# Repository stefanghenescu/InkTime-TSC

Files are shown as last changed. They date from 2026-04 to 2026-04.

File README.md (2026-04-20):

# InkTime TSC

## Block Diagram
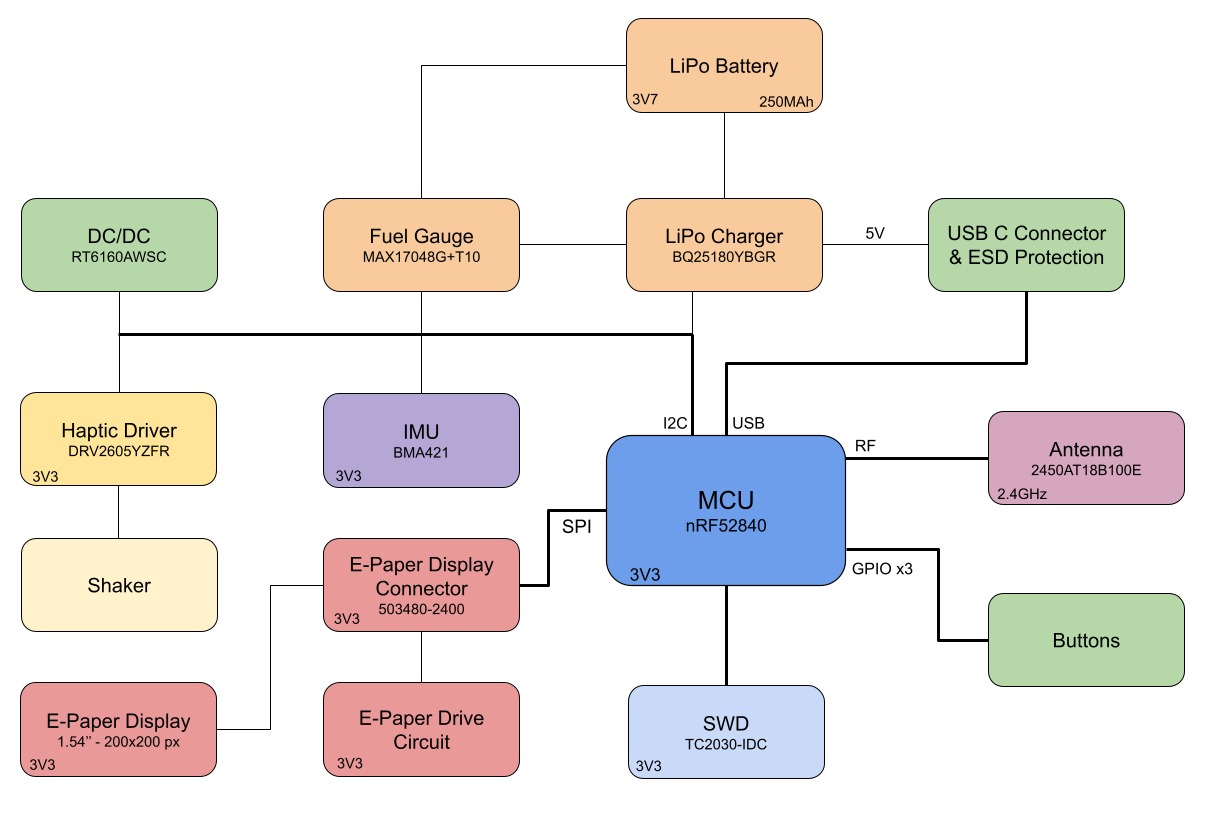
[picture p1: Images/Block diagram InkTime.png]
Block Diagram


---

## Bill of Materials (BOM)

| Name | Component Type | Package | Part Number / Value | Qty | JLCPCB Part Link | Datasheet Link |
| :--- | :--- | :--- | :--- | :--- | :--- | :--- |
| **U1** | MCU | AQFN-74 | NRF52840 | 1 | [View Part](https://jlcpcb.com/partdetail/NordicSemicon-NRF52840_QIAAR/C190794) | [View Datasheet](https://resources.ampheo.com/static/datasheets/nordic-semiconductor/nrf52840-qiaa-r-rev2.pdf) |
| **IC1** | LiPo Charger | DSBGA-8 | BQ25180YBGR | 1 | [View Part](https://jlcpcb.com/partdetail/TexasInstruments-BQ25180YBGR/C3682423) | [View Datasheet](https://www.ti.com/lit/ds/symlink/bq25180.pdf?ts=1776583277258) |
| **IC2** | Haptic Driver | DSBGA-9 | DRV2605YZFR | 1 | [View Part](https://jlcpcb.com/partdetail/TexasInstruments-DRV2605YZFR/C81079) | [View Datasheet](https://www.ti.com/lit/ds/symlink/drv2605.pdf) |
| **IC3** | IMU / Accelerometer | LGA-12 | BMA423 | 1 | [View Part](https://jlcpcb.com/partdetail/BoschSensortec-BMA421/C5242966) | [View Datasheet](https://files.pine64.org/doc/datasheet/pinetime/BST-BMA421-FL000.pdf) |
| **IC9** | DC/DC Converter | 15-WL-CSP | RT6160AWSC | 1 | [View Part](https://jlcpcb.com/partdetail/RichtekTech-RT6160AWSC/C7065276) | [View Datasheet](https://www.lcsc.com/datasheet/C7065276.pdf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) |
| **U3** | Fuel Gauge | TDFN-8 | MAX17048G+T10 | 1 | [View Part](https://jlcpcb.com/partdetail/2777647-MAX17048GT10/C2682616) | [View Datasheet](https://www.analog.com/media/en/technical-documentation/data-sheets/max17048-max17049.pdf) |
| **ANT1** | Chip Antenna | ANTC3216 | 2450AT18B100E | 1 | [View Part](https://jlcpcb.com/partdetail/JohansonDielectrics-2450AT18B100E/C2917717) | [View Datasheet](https://www.johansontechnology.com/docs/1187/2450AT18B100_X8XXogU.pdf) |
| **J1** | FPC Connector | 5034802400 | 503480-2400 | 1 | [View Part](https://jlcpcb.com/partdetail/MOLEX-5034802400/C122434) | [View Datasheet](https://www.mouser.com/datasheet/2/276/2/5034802400_FFC_FPC_CONNECTORS-1112921.pdf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) |
| **J2** | Debug Connector | TC2030IDC | TC2030-IDC | 1 | - | [View Datasheet](https://www.tag-connect.com/wp-content/uploads/bsk-pdf-manager/2019/12/TC2030-IDC-Datasheet-Rev-B.pdf) |
| **J4** | USB-C Connector | KH-TYPE-C-16P | KH-TYPE-C-16P | 1 | [View Part](https://jlcpcb.com/partdetail/Shenzhen_KinghelmElec-KH_TYPE_C16P/C709357) | [View Datasheet](https://www.lcsc.com/datasheet/C709357.pdf) |
| **Q1** | P-Channel MOSFET | SOT23-3 | DMG2305UX-7 | 1 | [View Part](https://jlcpcb.com/partdetail/DiodesIncorporated-DMG2305UX7/C150470) | [View Datasheet](https://www.lcsc.com/datasheet/C150470.pdf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) |
| **Q3** | N-Channel MOSFET | SC-70 / SOT-323 | SI1308EDL-T1-GE3 | 1 | [View Part](https://jlcpcb.com/partdetail/VishayIntertech-SI1308EDL_T1GE3/C469327) | [View Datasheet](https://www.lcsc.com/datasheet/C469327.pdf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) |
| **D2, D4, D5** | Schottky Diode | SOD-123 | MBR0530 | 3 | [View Part](https://jlcpcb.com/partdetail/78464-MBR0530/C77336) | [View Datasheet](https://www.onsemi.com/pdf/datasheet/mbr0530-d.pdf) |
| **D3** | ESD Protection | SOT23-6 | USBLC6-2SC6Y | 1 | [View Part](https://jlcpcb.com/partdetail/STMicroelectronics-USBLC62SC6Y/C2969755) | [View Datasheet](https://www.st.com/resource/en/datasheet/usblc6-2sc6y.pdf) |
| **SW_DN, SW_ENT, SW_UP** | Tactile Button | SMD | EVP-AKE31A | 3 | [View Part](https://jlcpcb.com/partdetail/PANASONIC-EVPAKE31A/C569760) | [View Datasheet](https://docs.rs-online.com/b6df/A700000008633059.pdf) |
| **X1** | Crystal | 2016 | 32MHz | 1 | [View Part](https://jlcpcb.com/partdetail/357115-X201232768KJD2SI/C383843) | [View Datasheet](https://www.lcsc.com/datasheet/C383843.pdf?spm=wm.sxq.inf.ggs___wm.ssy.bg.0.xh&) |lcsc_vid=RVILV1QAFgMLXlRXRFQPBVVeFgVaXwJQTwdfAlJXFAUxVlNRQVReX1FSQlVdUDsOAxUeFF5JWBYZEEoKFBINSQcJGk4eFQsCAgIaSgADAwAHC0slQ1BWUFVTQU8GEwkK |
| **X2** | Crystal | 3215 | 32.768kHz | 1 | [View Part](https://jlcpcb.com/partdetail/YXC_CrystalOscillators-X322532MOB4SI/C9009) | [View Datasheet](https://www.lcsc.com/datasheet/C9009.pdf?spm=wm.sxq.inf.ggs___wm.ssy.bg.0.xh&) |lcsc_vid=RVILV1QAFgMLXlRXRFQPBVVeFgVaXwJQTwdfAlJXFAUxVlNRQVReX1BTRFhZXjsOAxUeFF5JWBYZEEoKFBINSQcJGk4eFQsCAgIaSgADAwAHC0slRlheUF1SWQkaCgg%3D |
| **L1** | Inductor | 0402 | 3.9nH | 1 | [View Part](https://jlcpcb.com/partdetail/MurataElectronics-LQG15HS3N9S02D/C77109) | [View Datasheet](https://static.chipdip.ru/lib/273/DOC012273635.pdf) |
| **L2** | Inductor | 0402 | 10uH | 1 | [View Part](https://jlcpcb.com/partdetail/MurataElectronics-LQW15DN100M00D/C910650) | [View Datasheet](https://www.farnell.com/datasheets/2616941.pdf) |
| **L3** | Inductor | 0402 | 15nH | 1 | [View Part](https://jlcpcb.com/partdetail/MurataElectronics-LQG15HS15NJ02D/C86059) | [View Datasheet](https://eu.mouser.com/datasheet/3/76/3/JELF243B_0010.pdf) |
| **L5** | Inductor | 4828 | 744043680 | 1 | [View Part](https://jlcpcb.com/partdetail/MurataElectronics-LQG15HS27NJ02D/C12669) | [View Datasheet](https://search.murata.co.jp/Ceramy/image/img/P02/JELF243B-0010.pdf) |
| **L7** | Inductor | INDC2016 | FTC252012SR47MBCA | 1 | [View Part](https://jlcpcb.com/partdetail/MurataElectronics-LQW15CNR47K10D/C913544) | [View Datasheet](https://www.mouser.com/datasheet/2/281/1/JELF243A_0096-1380927.pdf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) |
| **SJ1** | Solder Jumper | SMD | Jumper | 1 | - | - |
| **R2, R3, R4** | Resistor | 0201 | 0Ω | 3 | [View Part](https://jlcpcb.com/partdetail/YAGEO-RC0201FR070RL/C106227) | [View Datasheet](https://www.mouser.com/catalog/specsheets/YAGEO_PYu_RC_Group_51_RoHS_L_12.pdf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) |
| **R1_EP_DR** | Resistor | 0201 | 0.47Ω | 1 | [View Part](https://jlcpcb.com/partdetail/21809-25121WF470LT4E/C21097) | [View Datasheet](https://www.royalohm.com/assets/pdf/products/smd/1.pdf) |
| **R_TYPE_SEL** | Resistor | 0201 | 2.2Ω | 1 | [View Part](https://jlcpcb.com/partdetail/YAGEO-RC0201FR072R2L/C138154) | [View Datasheet](https://www.mouser.com/catalog/specsheets/YAGEO_PYu_RC_Group_51_RoHS_L_12.pdf) |
| **R17, R18** | Resistor | 0201 | 3.3kΩ | 2 | [View Part](https://jlcpcb.com/partdetail/YAGEO-AC0201FR073K3L/C226534) | [View Datasheet](https://ro.mouser.com/datasheet/3/508/1/PYU_AC_51_ROHS_L.pdf) |
| **R1_USB, R2_USB** | Resistor | 0201 | 5.1kΩ | 2 | [View Part](https://jlcpcb.com/partdetail/YAGEO-RC0201JR075K1L/C163490) | [View Datasheet](https://yageogroup.com/component-documentation/download/specsheet/RC0201JR-075K1L) |
| **R2_EP_DR, R9, R_PWR_EPD** | Resistor | 0201 | 10kΩ | 3 | [View Part](https://jlcpcb.com/partdetail/TEConnectivity-CPF0201D10KC1/C4187156) | [View Datasheet](https://www.te.com/commerce/DocumentDelivery/DDEController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) |
| **C3, C4** | Capacitor | 0201 | 1pF | 2 | [View Part](https://jlcpcb.com/partdetail/MurataElectronics-GRM0335C1H1R0BA01D/C85893) | [View Datasheet](https://ro.mouser.com/datasheet/3/76/1/GRM0335C1H1R0BA01-01A.pdf) |
| **C1, C2, C17, C18** | Capacitor | 0201 | 12pF | 4 | [View Part](https://jlcpcb.com/partdetail/MurataElectronics-GRM0335C1H120JA01D/C85890) | [View Datasheet](https://docs.rs-online.com/0636/A700000008615927.pdf) |
| **C11** | Capacitor | 0201 | 100pF | 1 | [View Part](https://jlcpcb.com/partdetail/MurataElectronics-GRM0335C1E101JA01D/C76917) | [View Datasheet](https://docs.rs-online.com/3c16/A700000008615521.pdf) |
| **C9** | Capacitor | 0201 | 820pF | 1 | [View Part](https://jlcpcb.com/partdetail/197002-GRM033R71E821KA01D/C185597) | [View Datasheet](https://docs.rs-online.com/7ce9/A700000008614975.pdf) |
| **C10, C13, C16, C22** | Capacitor | 0201 | 47nF | 4 | [View Part](https://jlcpcb.com/partdetail/MurataElectronics-GRM033R60J473KE19D/C85925) | [View Datasheet](https://datasheet.octopart.com/GRM033R60J473KE19D-Murata-datasheet-44105416.pdf) |
| **C5, C7, C8, C12, C19** | Capacitor | 0201 | 100nF | 5 | [View Part](https://jlcpcb.com/partdetail/MurataElectronics-GRM033R60J104KE19D/C76928) | [View Datasheet](https://search.murata.co.jp/Ceramy/image/img/A01X/G101/ENG/GRM033R60J104KE19-01.pdf) |
| **C23, C27, C29, C30, C31, C32, C34, C37, C38, C42** | Capacitor | 0201 | GRM011R60J152KE01L | 10 | [View Part](https://jlcpcb.com/parts/componentSearch?searchTxt=GRM011R60J152KE01L) | [View Datasheet](https://datasheet.octopart.com/GRM011R60J152KE01L-Murata-datasheet-138731756.pdf) |
| **EPD_C5** | Capacitor | 0201 | 0.1uF/50V | 1 | [View Part](https://jlcpcb.com/partdetail/6103901-500R07W104KV4T_0_1uF50v/C5337557) | [View Datasheet](https://www.mouser.com/catalog/specsheets/johanson_joha-s-a0008490164-1.pdf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) |
| **C15** | Capacitor | 0402 | 1.0uF | 1 | [View Part](https://jlcpcb.com/partdetail/MurataElectronics-GRM155R60J105KE19D/C15684) | [View Datasheet](https://datasheet4u.com/pdf/1279553/GRM155R60J105KE19D.pdf) |
| **C6, C14, C20, C21, C43** | Capacitor | 0402 | 4.7uF | 5 | [View Part](https://jlcpcb.com/partdetail/MurataElectronics-GRM155R60J475KE96D/C76995) | [View Datasheet](https://www.lcsc.com/datasheet/C76995.pdf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) |
| **C2-EP-DR** | Capacitor | 0402 | 4.7uF/25V | 1 | [View Part](https://jlcpcb.com/partdetail/DMBJ-RVT1E4R7M0405_4_7UF25V/C970600) | [View Datasheet](https://www.lcsc.com/datasheet/C2895731.pdf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) |
| **C1-EP-DR, C24, C39** | Capacitor | 0402 | 10uF | 3 | [View Part](https://jlcpcb.com/partdetail/MurataElectronics-GRM155R60J106ME44D/C76991) | [View Datasheet](https://www.mouser.com/catalog/specsheets/murata_03052018_GRM_Series_1.pdf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) |
| **C25, C33** | Capacitor | 0402 | 22uF | 2 | [View Part](https://jlcpcb.com/partdetail/408393-GRM155R60J226ME11D/C415703) | [View Datasheet](https://ro.mouser.com/datasheet/3/76/2/GRM155R60J226ME11_01A.pdf) |
| **EPD_C1, EPD_C2, EPD_C6–12**| Capacitor | 0402 | 1uF/50V | 9 | [View Part](https://jlcpcb.com/partdetail/25795-0201WMJ0100TCE/C25052) | [View Datasheet](https://www.lcsc.com/datasheet/C25052.pdf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) |
| **TP_3.3V, TP_3V3, TP_BAT_GND, TP_GND, TP_ON, TP_OP, TP_RESET, TP_SCL, TP_SDA, TP_SWDCLK, TP_SWDIO, TP_SWO, TP_VBAT, TP_VREG** | Test Pad | TP20R | Test Pad | 14 | - | - |

---

## Hardware Functionality

This section describes the main hardware subsystems of the InkTime smartwatch, focusing on component choices, overall architecture, and how the design is optimized for low power consumption.

---

### 1. Core Processing & RF

**Microcontroller (MCU):**  
The system is built around the **Nordic nRF52840 (ARM Cortex-M4F)**. It was chosen mainly because it already includes Bluetooth Low Energy (BLE 5.0) and USB support, so no extra external communication chips are needed.

**Clocking System:**  
A dual-crystal setup is used:
- 32 MHz crystal for normal processing and wireless communication  
- 32.768 kHz crystal for the real-time clock (RTC) during low-power sleep modes  

This allows the system to keep accurate time while consuming very little energy when idle.

**Wireless Connectivity:**  
A small 2.4 GHz chip antenna is placed at the edge of the PCB. A matching network is used to improve RF performance and ensure stable BLE communication with a phone or other devices.

---

### 2. Power Management Architecture

The power system is designed to keep energy usage as low as possible while maintaining stable operation.

**Charging & Input:**  
Power is supplied through a USB-C connector, with ESD protection for safety. A **BQ25180 power management IC** handles LiPo charging and automatically switches between USB power and battery operation.

**Voltage Regulation:**  
Since battery voltage changes during discharge, an **RT6160 converter** is used to generate a stable 3.3V rail. This ensures the system works reliably across the entire battery range without brownouts.

**Battery Monitoring:**  
A **MAX17048 fuel gauge** estimates battery level. It reads voltage directly, avoiding the need for a current-sense resistor, which helps reduce power loss and saves space.

---

### 3. Display Subsystem

**E-Paper Panel:**  
The visual output is handled by an e-paper display, selected because it offers very good readability in sunlight and keeps the image without consuming power.

**Power Control:**  
The display requires higher voltages for operation, but it is only powered during refresh cycles. The rest of the time, the MCU completely switches it off using a MOSFET-based power gating circuit. This significantly reduces idle power consumption.

---

### 4. Sensing & User Interaction

**Motion Tracking:**  
A BMA42x IMU is used to detect motion, steps, and general activity. Instead of being read continuously, it can generate interrupt signals that wake the MCU only when movement is detected (for example, wrist movement).

**Haptic Feedback:**  
A DRV2605 haptic driver controls a vibration motor. Rather than generating signals manually, the MCU only triggers predefined vibration patterns stored in the driver.

**Tactile Inputs:**  
Three physical buttons are used for user interaction. They include hardware debounce filtering so that inputs remain stable without needing constant software correction.

---

### 5. Communication Buses

To keep the PCB simple and organized, communication is divided based on speed requirements:

**Shared I2C Bus:**  
Used for low-speed peripherals such as the IMU, fuel gauge, charger IC, and haptic driver. This reduces the number of required MCU pins and keeps routing simple.

**Dedicated SPI Bus:**  
Used only for the e-paper display, since it needs higher data throughput during screen updates. Additional control signals (reset, data/command, busy) are used to manage the display operation.

**Debug Interface:**  
Firmware programming and debugging are handled through a SWD interface, which provides full access without requiring a large permanent header on the PCB.

---

### 6. Power Consumption (Estimation)

The system is mainly optimized for low-power operation, with most components active only for short periods and the MCU spending most of the time in sleep mode.

Typical currents:
- nRF52840 active: ~10–15 mA  
- E-paper refresh (peak): ~20–40 mA (short bursts)  
- IMU: ~0.1 mA  
- Haptic motor: ~50–70 mA (very short pulses)  
- Deep sleep: ~2–5 µA  

With a ~180 mAh LiPo battery and a mostly idle usage pattern (sleep + occasional updates), the estimated battery life is around **5 days**.

---
## nRF52840 Pin Mapping
| Pin | Component / Block | Purpose |
|:--- |:--- |:--- |
| **---** | **Power & Regulation** | **---** |
| **VDD** | MCU Power | Main 3.3V supply for the microcontroller. |
| **VDDH** | MCU Power | High-voltage supply input. |
| **VSS / VSS_PA / VSS_PAD** | Ground | Ground connections for MCU and RF stages. |
| **DEC[1..6] / DEC3V3** | Internal Regulation | Decoupling pins for internal regulators and 3.3V rail stability. |
| **DCC** | DC/DC | Support pins for the internal DC/DC converter. |
| **---** | **Clock & RF** | **---** |
| **XC1 / XC2** | System Clock | 32 MHz crystal oscillator for main operation. |
| **XL1 / XL2** | System Clock | 32.768 kHz crystal for RTC and low-power modes. |
| **ANT** | Antenna | Connection to the 2.4 GHz RF output. |
| **---** | **E-Paper Display (SPI)** | **---** |
| **P0.02** | E-Paper Display | SPI clock (SCK) for display communication. |
| **P0.03** | E-Paper Display | SPI data line (MOSI) for sending pixel data. |
| **P0.05** | E-Paper Display | Chip select to enable the display on the SPI bus. |
| **P0.15** | E-Paper Display | Selects between command and data mode. |
| **P0.16** | E-Paper Display | Hardware reset for the display controller. |
| **P0.17** | E-Paper Display | Busy signal used to synchronize display updates. |
| **P1.01** | E-Paper Display | Controls power gating for the display. |
| **---** | **I2C Bus** | **---** |
| **P0.06** | IMU, Fuel Gauge, Charger, Haptic Driver | Shared I2C data line (SDA) for all peripherals. |
| **P0.07** | IMU, Fuel Gauge, Charger, Haptic Driver | Shared I2C clock line (SCL). |
| **---** | **Sensors & Power ICs** | **---** |
| **P0.08** | IMU | Primary interrupt for motion and wake-up events. |
| **P1.08** | IMU | Secondary interrupt for advanced events. |
| **P0.11** | LiPo Charger | Interrupt line for charge status and fault detection. |
| **P0.10** | Fuel Gauge | Alert signal for low battery or voltage thresholds. |
| **---** | **User Interface** | **---** |
| **P0.12** | Haptic Driver | Enable signal for the vibration motor driver. |
| **P0.13** | Button | User input |
| **P0.14** | Button | User input |
| **P1.02** | Button | User input |
| **---** | **System & SWD** | **---** |
| **P0.18** | System | Global reset line for the microcontroller. |
| **SWDIO** | SWD Interface | Data line for programming and debugging. |
| **SWDCLK** | SWD Interface | Clock line for the debugging interface. |
| **P1.00** | SWD Interface | SWO trace output for advanced debugging. |
| **---** | **USB Interface** | **---** |
| **D+ / D-** | USB Interface | Differential data lines for USB communication. |
| **VBUS** | USB Interface | Used to detect USB connection. |
---
*Note: All other nRF52840 pins not listed in this table are unused.*

## Renders

### PCB Renderings
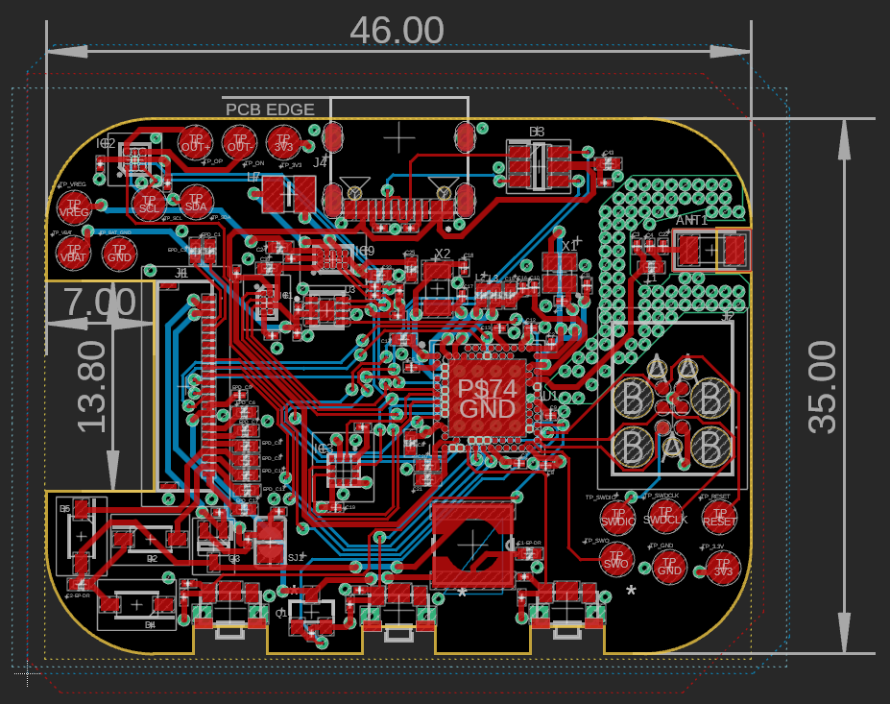
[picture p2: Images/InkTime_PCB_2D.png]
PCB 2D

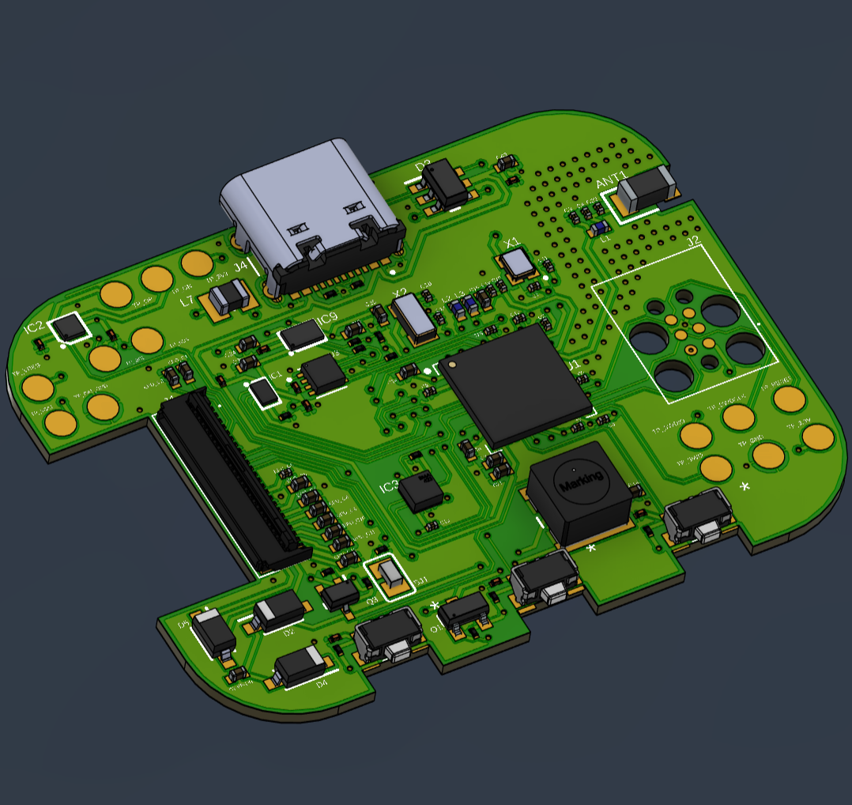
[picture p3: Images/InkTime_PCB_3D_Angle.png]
PCB 3D


### Component Placement in Case
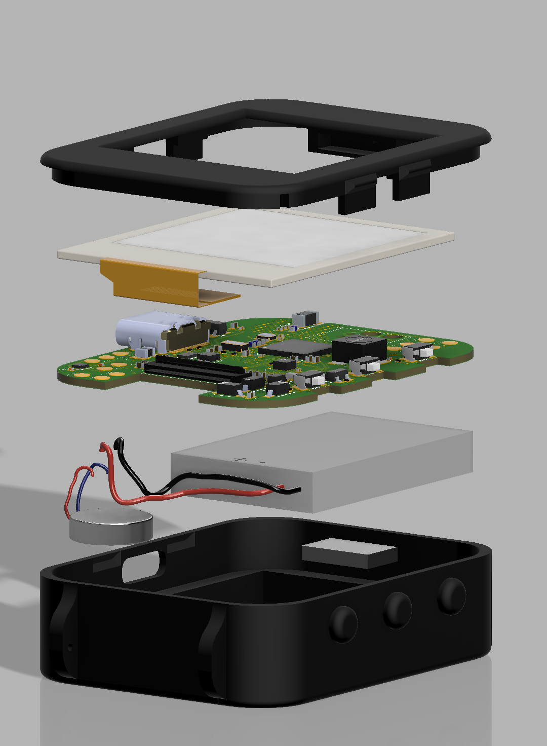
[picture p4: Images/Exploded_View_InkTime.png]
Case Fit

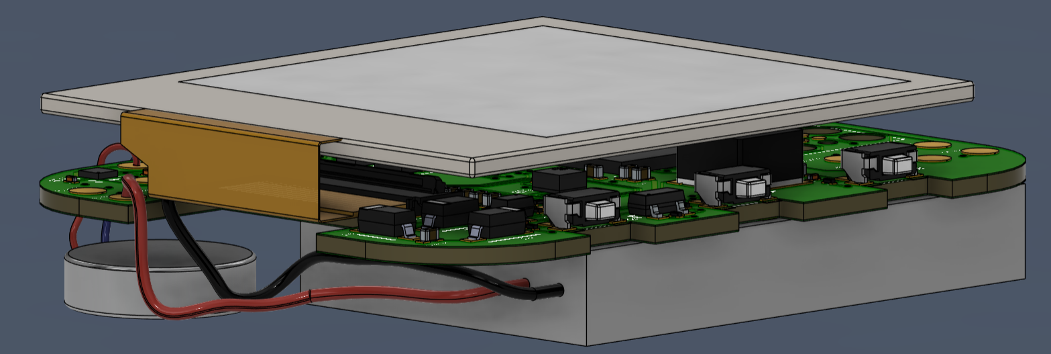
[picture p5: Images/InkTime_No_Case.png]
Components


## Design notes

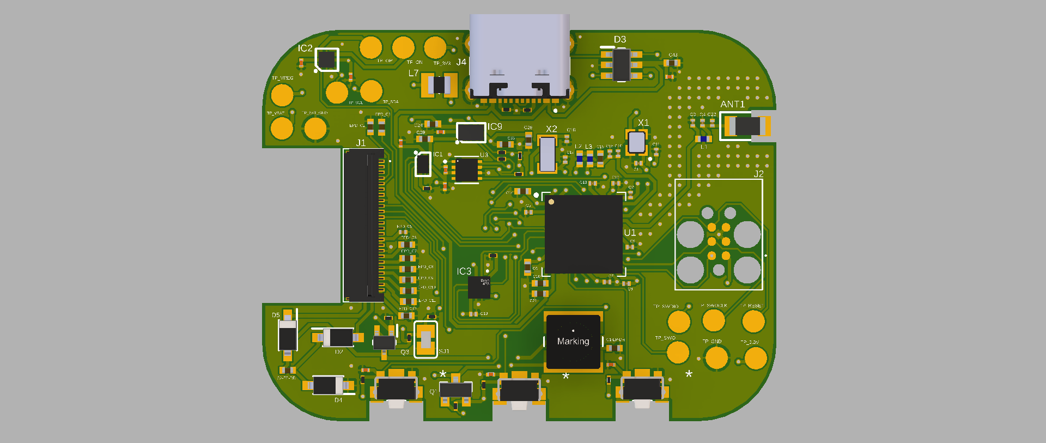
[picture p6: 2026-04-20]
Images/InkTime_PCB_3D.png

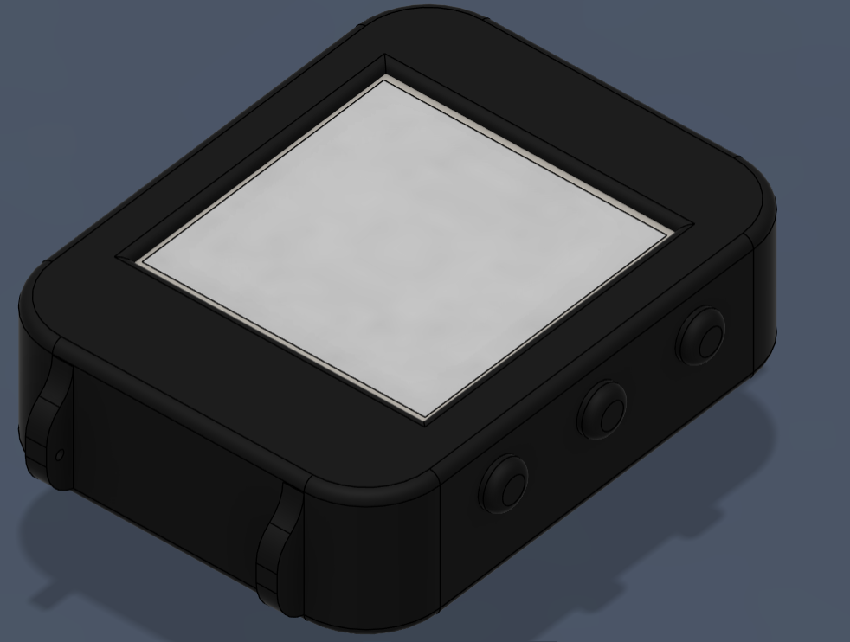
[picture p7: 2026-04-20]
Images/InkTime.png

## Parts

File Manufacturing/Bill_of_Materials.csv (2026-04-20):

Qty | Value | Device | Package | Parts | Description | ARROW_PART_NUMBER | ARROW_PRICE-STOCK | AVAILABILITY | CHECK_PRICES | COPYRIGHT | DESCRIPTION | DIGI-KEY_PART_NUMBER_1 | DIGI-KEY_PART_NUMBER_2 | DIGI-KEY_PART_NUMBER_3 | HEIGHT | JLCPCB | MANUFACTURER_NAME | MANUFACTURER_PART_NUMBER | MF | MFR_NAME | MOUSER_PART_NUMBER | MOUSER_PRICE-STOCK | MP | PACKAGE | POPULARITY | PRICE | PROD_ID | PURCHASE-URL | SNAPEDA_LINK | TP_SIGNAL_NAME | VALUE
1 |  | ESP32_C6_LIBRARY_7_JUMPER_SJ | ESP32_C6_LIBRARY_7_JUMPER_SJ | SJ1 | SMD solder JUMPER |  |  |  |  |  |  |  |  |  |  |  |  |  |  |  |  |  |  |  | 3
3 | 0 | CPF0201D7K68C1_CPF0201D7K68C1 | CPF0201D7K68C1_0201 | R2, R3, R4 | 7.68k 0201 Thin Film Surface Mount Fixed Resistor +/-0.5% 0.031W CPF0201D7K68C1
4 | 0.1uF | GRM011R60J152KE01L_1_GRM011R60J152KE01L | GRM011R60J152KE01L_1_0201 | C23, C27, C34, C42 | Check availability
1 | 0.1uF/50V | NORDIC_NRF_3_CAPACITOR_0201_L | NORDIC_NRF_3_RESC0201_L | EPD_C5 | Generic chip capacitor
1 | 0.47 | CPF0201D7K68C1_CPF0201D7K68C1 | CPF0201D7K68C1_0201 | R1_EP_DR | 7.68k 0201 Thin Film Surface Mount Fixed Resistor +/-0.5% 0.031W CPF0201D7K68C1
1 | 1.0µF | NORDIC_NRF_3_CAPACITOR_0402_L | NORDIC_NRF_3_RESC0402_L | C15 | Generic chip capacitor
5 | 100nF | NORDIC_NRF_3_CAPACITOR_0201_L | NORDIC_NRF_3_RESC0201_L | C5, C7, C8, C12, C19 | Generic chip capacitor
1 | 100pF | NORDIC_NRF_3_CAPACITOR_0201_L | NORDIC_NRF_3_RESC0201_L | C11 | Generic chip capacitor
3 | 10K | CPF0201D7K68C1_CPF0201D7K68C1 | CPF0201D7K68C1_0201 | R2_EP_DR, R9, R_PWR_EPD | 7.68k 0201 Thin Film Surface Mount Fixed Resistor +/-0.5% 0.031W CPF0201D7K68C1
3 | 10k | CPF0201D7K68C1_CPF0201D7K68C1 | CPF0201D7K68C1_0201 | R1, R7, R8 | 7.68k 0201 Thin Film Surface Mount Fixed Resistor +/-0.5% 0.031W CPF0201D7K68C1
3 | 10uF | NORDIC_NRF_3_CAPACITOR_0402_L | NORDIC_NRF_3_RESC0402_L | C1-EP-DR, C24, C39 | Generic chip capacitor
1 | 10µH | NORDIC_NRF_2_INDUCTOR_0402_L | NORDIC_NRF_2_RESC0402_L | L2 | Generic chip inductor
4 | 12pF | NORDIC_NRF_3_CAPACITOR_0201_L | NORDIC_NRF_3_RESC0201_L | C1, C2, C17, C18 | Generic chip capacitor
1 | 15nH | NORDIC_NRF_2_INDUCTOR_0402_L | NORDIC_NRF_2_RESC0402_L | L3 | Generic chip inductor
2 | 1pF | NORDIC_NRF_3_CAPACITOR_0201_L | NORDIC_NRF_3_RESC0201_L | C3, C4 | Generic chip capacitor
6 | 1uF | GRM011R60J152KE01L_1_GRM011R60J152KE01L | GRM011R60J152KE01L_1_0201 | C29, C30, C31, C32, C37, C38 | Check availability
9 | 1uF/50V | NORDIC_NRF_3_CAPACITOR_0402_L | NORDIC_NRF_3_RESC0402_L | EPD_C1, EPD_C2, EPD_C6, EPD_C7, EPD_C8, EPD_C9, EPD_C10, EPD_C11, EPD_C12 | Generic chip capacitor
1 | 2.2 | CPF0201D7K68C1_CPF0201D7K68C1 | CPF0201D7K68C1_0201 | R_TYPE_SEL | 7.68k 0201 Thin Film Surface Mount Fixed Resistor +/-0.5% 0.031W CPF0201D7K68C1
3 | 2025-10-22_07-23-44_LIBRARY_EVP-AKE31ASW_EVP-AKE31A_PAN | 2025-10-22_07-23-44_LIBRARY_EVP-AKE31ASW_EVP-AKE31A_PAN | 2025-10-22_07-23-44_LIBRARY_SW_EVP-AKE31A_PAN | SW_DN, SW_ENT, SW_UP |  |  |  |  |  | Copyright (C) 2025 Ultra Librarian. All rights reserved. |  | P123437TR-ND | P123437CT-ND | P123437DKR-ND |  |  | Panasonic | EVP-AKE31A
1 | 20V/4.2A/52mO/1.4W | ESP32_C6_LIBRARY_4_ESP32_WROVER_SPARKFUN-DISCRETESEMI_MOSFET_PCH-DMG2305UX-7 | ESP32_C6_LIBRARY_4_ESP32_C6_LIBRARY_4_ESP32_C6_LIBRARY_4_ESP32_C6_LIBRARY_4_ESP32_WROVER_SPARKFUN-DISCRETESEMI_SOT23-3 | Q1 | P-channel MOSFETs |  |  |  |  |  |  |  |  |  |  |  |  |  |  |  |  |  |  |  |  |  | TRAN-14388 |  |  |  | 20V/4.2A/52mO/1.4W
2 | 22uF | NORDIC_NRF_3_CAPACITOR_0402_L | NORDIC_NRF_3_RESC0402_L | C25, C33 | Generic chip capacitor
1 | 2450AT18B100E | 2450AT18B100E_2450AT18B100E | 2450AT18B100E_ANTC3216X140N | ANT1 | Antennas 2.45GHz ANTENNA | 2450AT18B100E | https://www.arrow.com/en/products/2450at18b100e/johanson-dielectrics?utm_currency=USD&region=nac |  |  |  | Antennas 2.45GHz ANTENNA |  |  |  | 1.4mm |  | JOHANSON TECHNOLOGY | 2450AT18B100E |  |  | 609-2450AT18B100E | https://www.mouser.co.uk/ProductDetail/Johanson-Technology/2450AT18B100E?qs=yCnrNFeXz%252Bh5MFsFIXGZGA%3D%3D
1 | 3.9nH | NORDIC_NRF_2_INDUCTOR_0402_L | NORDIC_NRF_2_RESC0402_L | L1 | Generic chip inductor
1 | 32.768kHz | NORDIC_NRF_1_XTAL_32KHZ | NORDIC_NRF_1_XTAL_3215_N | X2
1 | 32MHz | NORDIC_NRF_XTAL_32MHZ | NORDIC_NRF_BT-XTAL_2016_N | X1
2 | 3K3 | CPF0201D7K68C1_CPF0201D7K68C1 | CPF0201D7K68C1_0201 | R17, R18 | 7.68k 0201 Thin Film Surface Mount Fixed Resistor +/-0.5% 0.031W CPF0201D7K68C1
1 | 4.7uF | NORDIC_NRF_3_CAPACITOR_0402_L | NORDIC_NRF_3_RESC0402_L | C43 | Generic chip capacitor
1 | 4.7uF/25V | NORDIC_NRF_3_CAPACITOR_0402_L | NORDIC_NRF_3_RESC0402_L | C2-EP-DR | Generic chip capacitor
4 | 4.7µF | NORDIC_NRF_3_CAPACITOR_0402_L | NORDIC_NRF_3_RESC0402_L | C6, C14, C20, C21 | Generic chip capacitor
1 | 47nF | NORDIC_NRF_3_CAPACITOR_0201_L | NORDIC_NRF_3_RESC0201_L | C16 | Generic chip capacitor
1 | 503480-2400 | 503480-2400_503480-2400 | 503480-2400_5034802400 | J1 | FFC & FPC Connectors 0.5mm FPC RA SMT Dual Contact 24Ckt |  |  |  |  |  | FFC & FPC Connectors 0.5mm FPC RA SMT Dual Contact 24Ckt |  |  |  | 1.87mm |  | Molex | 503480-2400 |  |  | 538-503480-2400 | https://www.mouser.co.uk/ProductDetail/Molex/503480-2400?qs=OAhjpuo3Vu7efIoxFh9AOw%3D%3D
2 | 5K1 | CPF0201D7K68C1_CPF0201D7K68C1 | CPF0201D7K68C1_0201 | R1_USB, R2_USB | 7.68k 0201 Thin Film Surface Mount Fixed Resistor +/-0.5% 0.031W CPF0201D7K68C1
1 | 68uH | ESP32_C6_LIBRARY_2_744043680IND_4828-WE-TPC_WRE | ESP32_C6_LIBRARY_2_IND_4828-WE-TPC_WRE | L5 |  |  |  |  |  | Copyright (C) 2024 Ultra Librarian. All rights reserved. |  |  |  |  |  |  |  | 744043680 |  | Wurth Electronics
1 | 820pF | NORDIC_NRF_3_CAPACITOR_0201_L | NORDIC_NRF_3_RESC0201_L | C9 | Generic chip capacitor
1 | BMA421 | BMA423_BMA423 | BMA423_BMA423 | IC3 | Accelerometers Triaxial low-g 12bit Acceleration Sensor | BMA423 | https://www.arrow.com/en/products/bma423/bosch |  |  |  | Accelerometers Triaxial low-g 12bit Acceleration Sensor |  |  |  | 1mm |  | BOSCH | BMA423 |  |  | 262-BMA423 | https://www.mouser.co.uk/ProductDetail/Bosch-Sensortec/BMA423?qs=HXFqYaX1Q2xC%252BSgeGoX3mg%3D%3D
1 | BQ25180YBGR | BQ25180YBGR_BQ25180YBGR | BQ25180YBGR_BGA8C40P2X4_100X155X50 | IC1 | Charger IC Lithium Ion/Polymer, Lithium Iron Phosphate 8-DSBGA (1.6x1.1) | BQ25180YBGR | https://www.arrow.com/en/products/bq25180ybgr/texas-instruments?utm_currency=USD&region=nac |  |  |  | Charger IC Lithium Ion/Polymer | Lithium Iron Phosphate 8-DSBGA (1.6x1.1) |  |  |  | 0.5mm |  | Texas Instruments | BQ25180YBGR |  |  | 595-BQ25180YBGR | https://www.mouser.co.uk/ProductDetail/Texas-Instruments/BQ25180YBGR?qs=doiCPypUmgEWjAK%252BJAX6Tw%3D%3D
1 | DRV2605YZFR | DRV2605YZFR_DRV2605YZFR | DRV2605YZFR_BGA9C50P3X3_144X144X62 | IC2 | Haptic Driver for ERM/LRA with Built-In Library and Smart Loop Architecture | DRV2605YZFR | https://www.arrow.com/en/products/drv2605yzfr/texas-instruments?region=nac |  |  |  | Haptic Driver for ERM/LRA with Built-In Library and Smart Loop Architecture |  |  |  | 0.625mm |  | Texas Instruments | DRV2605YZFR
1 | FTC252012SR47MBCA | MLP2016SR47MT0S1_FTC252012SR47MBCA | MLP2016SR47MT0S1_INDC2016X100N | L7 | SMD / SMT Inductors (Coils), L=0.47?H, L x W x T : |  |  |  |  |  | SMD / SMT Inductors (Coils) | L=0.47?H | L x W x T : |  |  |  | 1mm | https://jlcpcb.com/partdetail/6763488-FTC252012SR47MBCA/C5832368 | TDK | FTC252012SR47MBCA
14 | HECTOR_WATCH_1_TPTP20R | HECTOR_WATCH_1_TPTP20R | HECTOR_WATCH_1_TP20R | TP_3.3V, TP_3V3, TP_BAT_GND, TP_GND, TP_ON, TP_OP, TP_RESET, TP_SCL, TP_SDA, TP_SWDCLK, TP_SWDIO, TP_SWO, TP_VBAT, TP_VREG | Test pad |  |  |  |  |  |  |  |  |  |  |  |  |  |  |  |  |  |  |  | 2
1 | KH-TYPE-C-16P | KH-TYPE-C-16P_KH-TYPE-C-16P | KH-TYPE-C-16P_KINGHELM_KH-TYPE-C-16P | J4 | Check availability |  |  | Not in stock | https://www.snapeda.com/parts/KH-TYPE-C-16P/Kinghelm/view-part/?ref=eda |  |  |  |  |  |  |  |  |  | kinghelm |  |  |  | KH-TYPE-C-16P | None |  | None |  |  | https://www.snapeda.com/parts/KH-TYPE-C-16P/Kinghelm/view-part/?ref=snap
1 | MAX17048G+T10 | ESP32_C6_LIBRARY_MAX17048G+T10 | ESP32_C6_LIBRARY_SON50P200X200X80-9N | U3 | Check availability |  |  | In Stock | https://www.snapeda.com/parts/MAX17048G+T10/Analog+Devices/view-part/?ref=eda |  | 3µA 1-Cell/2-Cell Fuel Gauge with ModelGauge |  |  |  |  |  |  |  | Analog Devices |  |  |  | MAX17048G+T10 | TDFN-8 Maxim |  | None |  | https://www.snapeda.com/api/url_track_click_mouser/?unipart_id=329239&manufacturer=Analog Devices&part_name=MAX17048G+T10&search_term=None | https://www.snapeda.com/parts/MAX17048G+T10/Analog+Devices/view-part/?ref=snap
3 | MBR0530 | ESP32_C6_LIBRARY_5_MBR0530 | ESP32_C6_LIBRARY_5_SOD3716X135N | D2, D4, D5 | ON SEMICONDUCTOR - MBR0530 - DIODE, SCHOTTKY, 0.5A, 30V, SOD-123 |  |  | In Stock | https://www.snapeda.com/parts/MBR0530/Onsemi/view-part/?ref=eda |  | Diode Schottky 30 V 500mA Surface Mount SOD-123 |  |  |  |  |  |  |  | ON Semiconductor |  |  |  | MBR0530 | SOD-123-2 ON Semiconductor |  | None |  | https://www.snapeda.com/api/url_track_click_mouser/?unipart_id=179458&manufacturer=ON Semiconductor&part_name=MBR0530&search_term=None | https://www.snapeda.com/parts/MBR0530/Onsemi/view-part/?ref=snap
3 | N.C. | NORDIC_NRF_3_CAPACITOR_0201_L | NORDIC_NRF_3_RESC0201_L | C10, C13, C22 | Generic chip capacitor
1 | NRF52840_QF | NORDIC_NRF_4_NRF52840_QF | NORDIC_NRF_4_AQFN50P700X700X85_HS-74N | U1 | nRF52840
1 | RT6160AWSC | RT6160AWSC_RT6160AWSC | RT6160AWSC_BGA15C40P3X5_140X230X60 | IC9 | Buck-Boost Regulator Positive Output Step-Up/Step-Down I2C DC-DC Controller IC 15-WL-CSP (BSC) (1.4x2.3) |  |  |  |  |  | Buck-Boost Regulator Positive Output Step-Up/Step-Down I2C DC-DC Controller IC 15-WL-CSP (BSC) (1.4x2.3) |  |  |  | 0.6mm |  | RICHTEK | RT6160AWSC |  |  | 835-RT6160AWSC | https://www.mouser.co.uk/ProductDetail/Richtek/RT6160AWSC?qs=amGC7iS6iy%2FLd9PSoixZXQ%3D%3D
1 | SI1308EDL-T1-GE3 | ESP32_C6_LIBRARY_6_SI1308EDL-T1-GE3 | ESP32_C6_LIBRARY_6_SOT65P210X110-3N | Q3 | MOSFET N-Ch 30V 1.5A TrenchFET SC70 Vishay Si1308EDL-T1-GE3 N-channel MOSFET Transistor, 1.5 A, 30 V, 3-Pin SC-70 |  |  | In Stock | https://www.snapeda.com/parts/SI1308EDL-T1-GE3/Vishay+Siliconix/view-part/?ref=eda |  | Si1308EDL-T1-GE3 N-channel MOSFET Transistor | 1.5 A | 30 V | 3-Pin SC-70 | Siliconix / Vishay SI1308EDL-T1-GE3 |  |  |  |  |  |  |  | Vishay Siliconix |  |  |  | SI1308EDL-T1-GE3 | SOT-323 Vishay Semiconductor |  | None |  | https://www.snapeda.com/api/url_track_click_mouser/?unipart_id=274603&manufacturer=Vishay Siliconix&part_name=SI1308EDL-T1-GE3&search_term=None
1 | TC2030-IDC | TC2030-IDC_TC2030-IDC | TC2030-IDC_TC2030IDC | J2 | CABLE ADAPTER 6 POS |  |  |  |  |  | CABLE ADAPTER 6 POS |  |  |  | 19mm |  | Tag Connect | TC2030-IDC
1 | USBLC6-2SC6Y | ESP32_C6_LIBRARY_3_USBLC6-2SC6Y | ESP32_C6_LIBRARY_3_SOT95P280X145-6N | D3 | Low Cap. ESD Protection Auto SOT-23-6 STMicroelectronics USBLC6-2SC6Y, Dual Uni-Directional TVS Diode Array, 6-Pin SOT-23 |  |  | In Stock | https://www.snapeda.com/parts/USBLC6-2SC6Y/STMicroelectronics/view-part/?ref=eda |  | 17V Clamp 5A (8/20µs) Ipp Tvs Diode Surface Mount SOT-23-6 |  |  |  |  |  |  |  | STMicroelectronics |  |  |  | USBLC6-2SC6Y | SOT-23-6 STMicroelectronics |  | None |  |  | https://www.snapeda.com/parts/USBLC6-2SC6Y/STMicroelectronics/view-part/?ref=snap

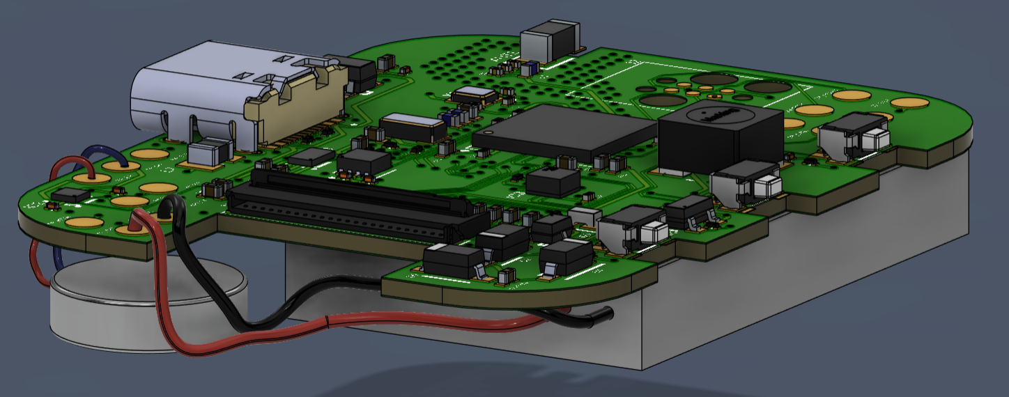
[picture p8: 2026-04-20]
Images/Components_InkTime.png

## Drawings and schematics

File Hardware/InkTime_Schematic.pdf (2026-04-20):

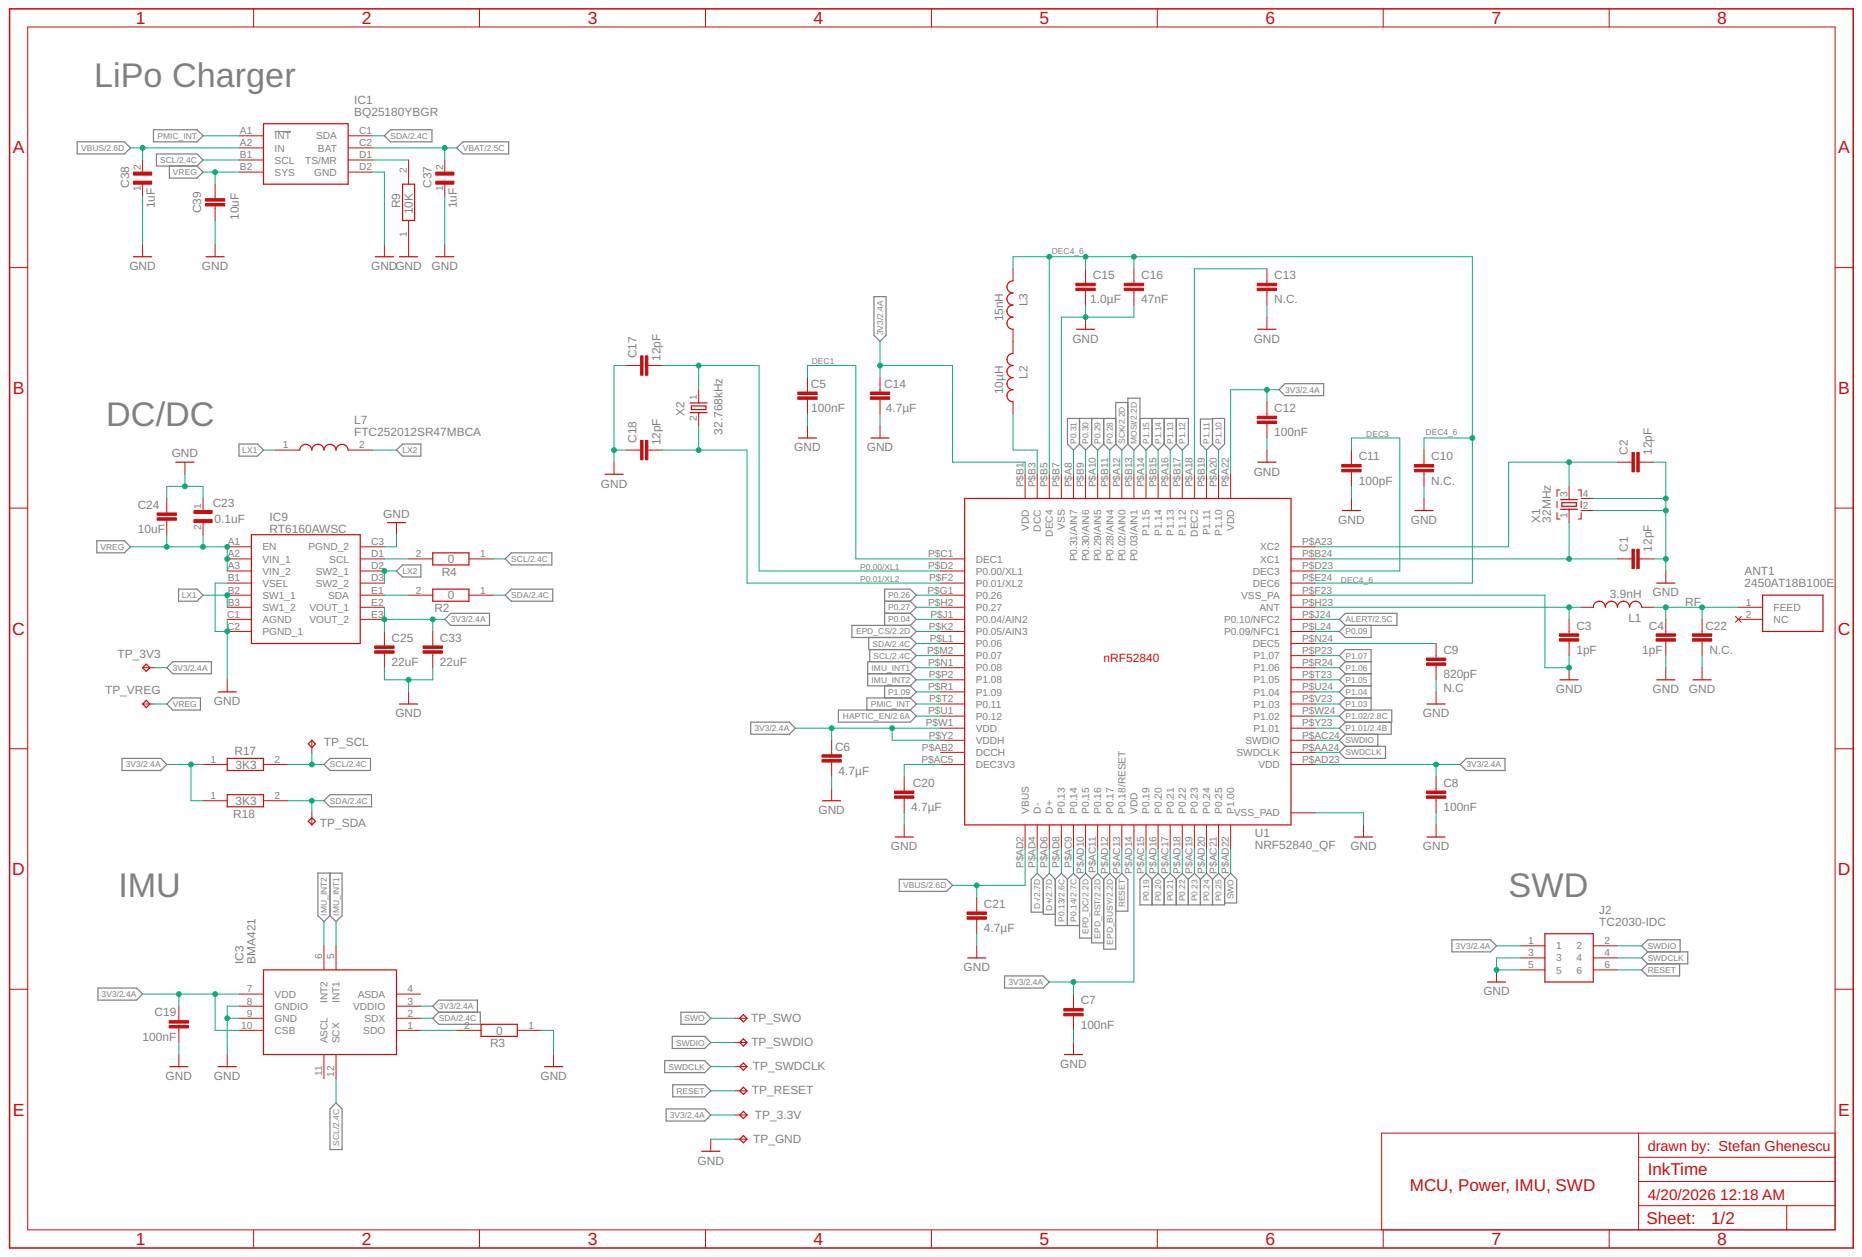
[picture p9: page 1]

MCU, Power, IMU, SWD

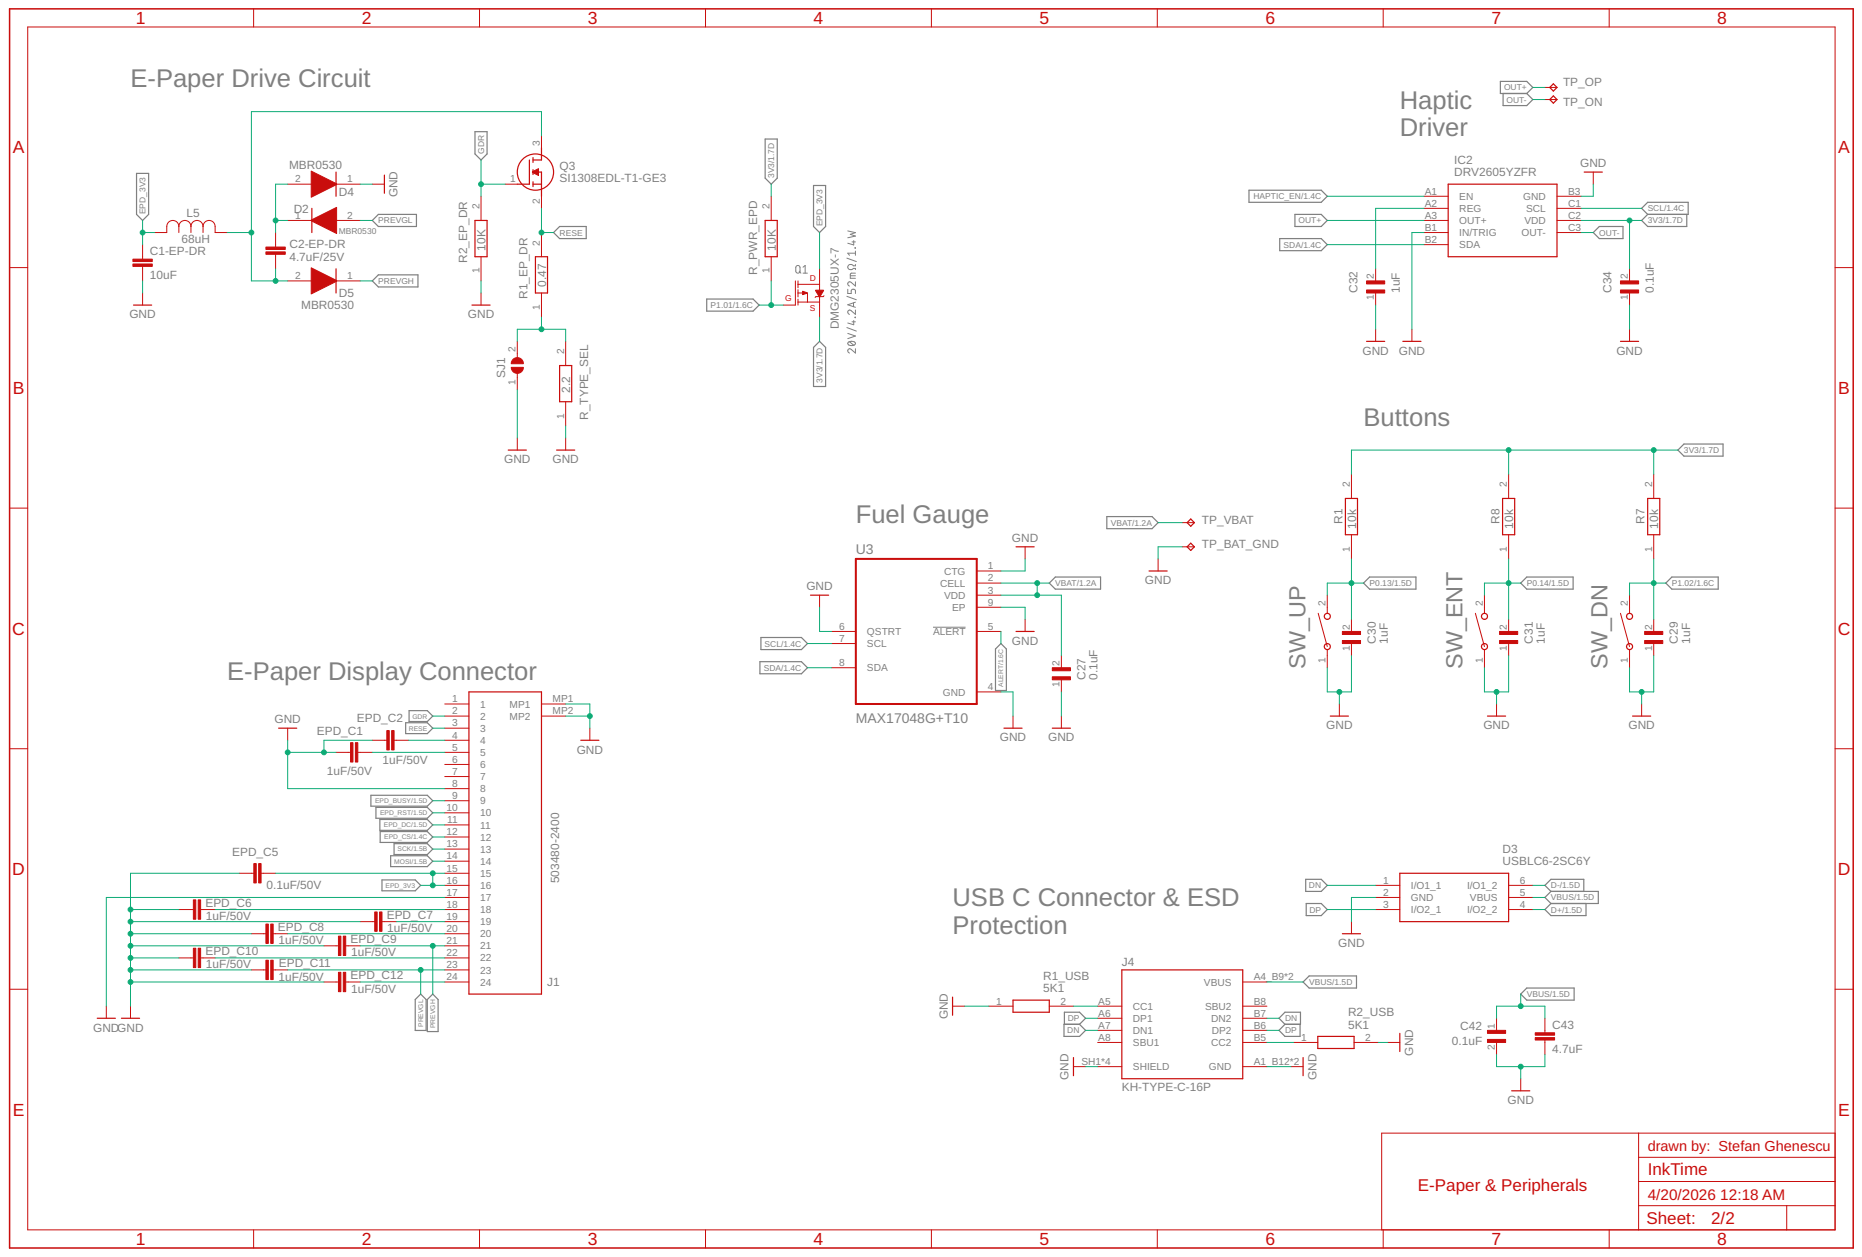
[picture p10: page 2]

1uF/50V | EPD_C7 19

EPD_C8 | 1uF/50V 20
1uF/50V | EPD_C9 21 | | GND

EPD_C10 | 1uF/50V | 22
1uF/50V | EPD_C11 | 23

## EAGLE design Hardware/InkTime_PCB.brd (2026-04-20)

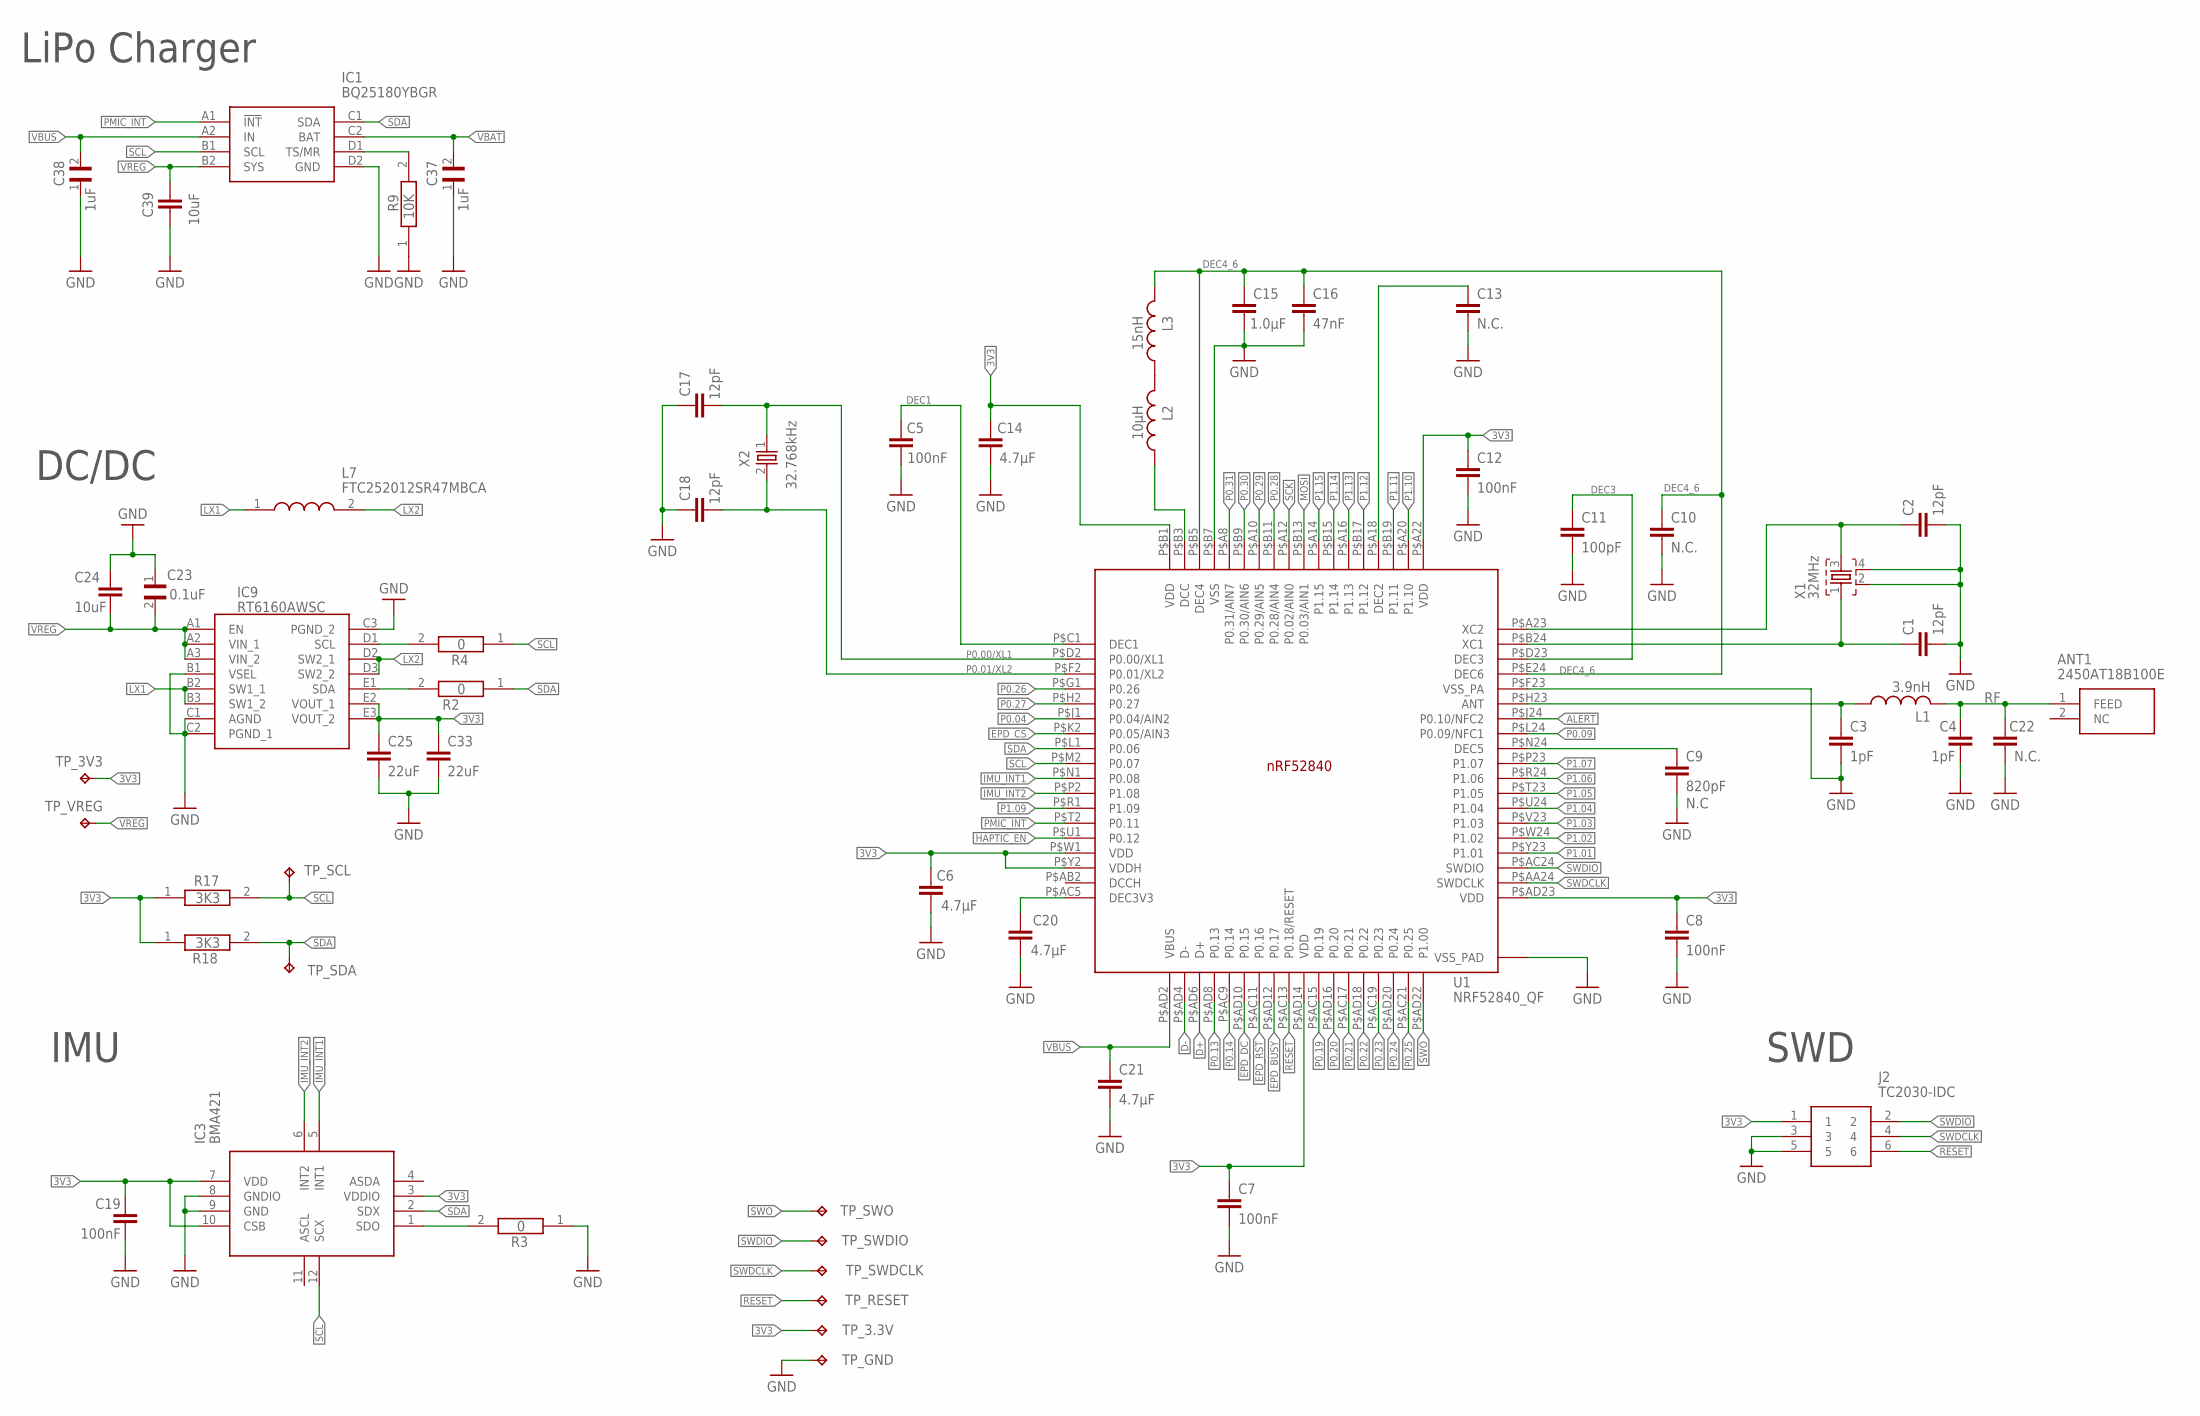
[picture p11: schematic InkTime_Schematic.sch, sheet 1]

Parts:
ANT1: 2450AT18B100E; 2450AT18B100E_ANTC3216X140N
C1, C2, C17, C18: 12pF; NORDIC_NRF_3_RESC0201_L
C3, C4: 1pF; NORDIC_NRF_3_RESC0201_L
C5, C7, C8, C12, C19: 100nF; NORDIC_NRF_3_RESC0201_L
C6, C14, C20, C21: 4.7µF; NORDIC_NRF_3_RESC0402_L
C9: 820pF; NORDIC_NRF_3_RESC0201_L
C10, C13, C22: N.C.; NORDIC_NRF_3_RESC0201_L
C11: 100pF; NORDIC_NRF_3_RESC0201_L
C15: 1.0µF; NORDIC_NRF_3_RESC0402_L
C16: 47nF; NORDIC_NRF_3_RESC0201_L
C23: 0.1uF; GRM011R60J152KE01L_1_0201
C24, C39: 10uF; NORDIC_NRF_3_RESC0402_L
C25, C33: 22uF; NORDIC_NRF_3_RESC0402_L
C37, C38: 1uF; GRM011R60J152KE01L_1_0201
IC1: BQ25180YBGR; BQ25180YBGR_BGA8C40P2X4_100X155X50
IC3: BMA421; BMA423_BMA423
IC9: RT6160AWSC; RT6160AWSC_BGA15C40P3X5_140X230X60
J2: TC2030-IDC; TC2030-IDC_TC2030IDC
L1: 3.9nH; NORDIC_NRF_2_RESC0402_L
L2: 10µH; NORDIC_NRF_2_RESC0402_L
L3: 15nH; NORDIC_NRF_2_RESC0402_L
L7: FTC252012SR47MBCA; MLP2016SR47MT0S1_INDC2016X100N
R2, R3, R4: 0; CPF0201D7K68C1_0201
R9: 10K; CPF0201D7K68C1_0201
R17, R18: 3K3; CPF0201D7K68C1_0201
TP_3.3V, TP_3V3: HECTOR_WATCH_1_TPTP20R; HECTOR_WATCH_1_TP20R
TP_GND: HECTOR_WATCH_1_TPTP20R; HECTOR_WATCH_1_TP20R
TP_RESET: HECTOR_WATCH_1_TPTP20R; HECTOR_WATCH_1_TP20R
TP_SCL: HECTOR_WATCH_1_TPTP20R; HECTOR_WATCH_1_TP20R
TP_SDA: HECTOR_WATCH_1_TPTP20R; HECTOR_WATCH_1_TP20R
TP_SWDCLK: HECTOR_WATCH_1_TPTP20R; HECTOR_WATCH_1_TP20R
TP_SWDIO: HECTOR_WATCH_1_TPTP20R; HECTOR_WATCH_1_TP20R
TP_SWO: HECTOR_WATCH_1_TPTP20R; HECTOR_WATCH_1_TP20R
TP_VREG: HECTOR_WATCH_1_TPTP20R; HECTOR_WATCH_1_TP20R
U1: NRF52840_QF; NORDIC_NRF_4_AQFN50P700X700X85_HS-74N
X1: 32MHz; NORDIC_NRF_BT-XTAL_2016_N
X2: 32.768kHz; NORDIC_NRF_1_XTAL_3215_N

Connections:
3V3: C6.2, C7.1, C8.1, C12.1, C14.2, C19.1, C25.1, C33.1, IC3.3 (VDDIO), IC3.7 (VDD), IC3.10 (CSB), IC9.E2 (VOUT_1), IC9.E3 (VOUT_2), J2.1, R17.1, R18.1, TP_3.3V.TP, TP_3V3.TP, U1.P$A22 (VDD), U1.P$AD14 (VDD), U1.P$AD23 (VDD), U1.P$B1 (VDD), U1.P$W1 (VDD), U1.P$Y2 (VDDH); also elsewhere on the board
ALERT: U1.P$J24 (P0.10/NFC2); also elsewhere on the board
D+: U1.P$AD6 (D+); also elsewhere on the board
D-: U1.P$AD4 (D-); also elsewhere on the board
EPD_BUSY: U1.P$AD12 (P0.17); also elsewhere on the board
EPD_CS: U1.P$K2 (P0.05/AIN3); also elsewhere on the board
EPD_DC: U1.P$AD10 (P0.15); also elsewhere on the board
EPD_RST: U1.P$AC11 (P0.16); also elsewhere on the board
GND: C1.2, C2.2, C3.2, C4.2, C5.1, C6.1, C7.2, C8.2, C9.2, C10.2, C11.2, C12.2, C13.2, C14.1, C15.2, C16.2, C17.1, C18.1, C19.2, C20.1, C21.2, C22.2, C23.1, C24.1, C25.2, C33.2, C37.1, C38.1, C39.2, IC1.D2 (GND), IC3.8 (GNDIO), IC3.9 (GND), IC9.B1 (VSEL), IC9.C1 (AGND), IC9.C2 (PGND_1), IC9.C3 (PGND_2), J2.3, J2.5, R3.1, R9.1, TP_GND.TP, U1.P$74 (VSS_PAD), U1.P$75 (VSS_PAD), U1.P$76 (VSS_PAD), U1.P$77 (VSS_PAD), U1.P$78 (VSS_PAD), U1.P$79 (VSS_PAD), U1.P$80 (VSS_PAD), U1.P$81 (VSS_PAD), U1.P$82 (VSS_PAD), U1.P$83 (VSS_PAD), U1.P$84 (VSS_PAD), U1.P$85 (VSS_PAD), U1.P$86 (VSS_PAD), U1.P$87 (VSS_PAD), U1.P$88 (VSS_PAD), U1.P$89 (VSS_PAD), U1.P$90 (VSS_PAD), U1.P$B7 (VSS), U1.P$F23 (VSS_PA), X1.2, X1.4; also elsewhere on the board
HAPTIC_EN: U1.P$U1 (P0.12); also elsewhere on the board
IMU_INT1: IC3.5 (INT1), U1.P$N1 (P0.08)
IMU_INT2: IC3.6 (INT2), U1.P$P2 (P1.08)
LX1: IC9.B2 (SW1_1), IC9.B3 (SW1_2), L7.1
LX2: IC9.D2 (SW2_1), IC9.D3 (SW2_2), L7.2
MOSI: U1.P$B13 (P0.03/AIN1); also elsewhere on the board
unnamed: IC1.D1 (TS/MR), R9.2
unnamed: L2.1, U1.P$B3 (DCC)
unnamed: IC9.D1 (SCL), R4.2
unnamed: IC9.E1 (SDA), R2.2
unnamed: IC3.1 (SDO), R3.2
unnamed: C20.2, U1.P$AC5 (DEC3V3)
unnamed: L2.2, L3.1
unnamed: C13.1, U1.P$A18 (DEC2)
unnamed: C5.2, U1.P$C1 (DEC1)
unnamed: C10.1, C15.1, C16.1, L3.2, U1.P$B5 (DEC4), U1.P$E24 (DEC6)
unnamed: C11.1, U1.P$D23 (DEC3)
unnamed: C17.2, U1.P$D2 (P0.00/XL1), X2.1
unnamed: C18.2, U1.P$F2 (P0.01/XL2), X2.2
unnamed: C9.1, U1.P$N24 (DEC5)
unnamed: C3.1, L1.1, U1.P$H23 (ANT)
unnamed: ANT1.1 (FEED), C4.1, C22.1, L1.2
unnamed: C1.1, U1.P$B24 (XC1), X1.1
unnamed: C2.1, U1.P$A23 (XC2), X1.3
P0.04: U1.P$J1 (P0.04/AIN2)
P0.09: U1.P$L24 (P0.09/NFC1)
P0.13: U1.P$AD8 (P0.13); also elsewhere on the board
P0.14: U1.P$AC9 (P0.14); also elsewhere on the board
P0.19: U1.P$AD16 (P0.20)
P0.20: U1.P$AC15 (P0.19)
P0.21: U1.P$AC17 (P0.21)
P0.22: U1.P$AD18 (P0.22)
P0.23: U1.P$AC19 (P0.23)
P0.24: U1.P$AD20 (P0.24)
P0.25: U1.P$AC21 (P0.25)
P0.26: U1.P$G1 (P0.26)
P0.27: U1.P$H2 (P0.27)
P0.28: U1.P$B11 (P0.28/AIN4)
P0.29: U1.P$A10 (P0.29/AIN5)
P0.30: U1.P$B9 (P0.30/AIN6)
P0.31: U1.P$A8 (P0.31/AIN7)
P1.01: U1.P$Y23 (P1.01); also elsewhere on the board
P1.02: U1.P$W24 (P1.02); also elsewhere on the board
P1.03: U1.P$V23 (P1.03)
P1.04: U1.P$U24 (P1.04)
P1.05: U1.P$T23 (P1.05)
P1.06: U1.P$R24 (P1.06)
P1.07: U1.P$P23 (P1.07)
P1.09: U1.P$R1 (P1.09)
P1.10: U1.P$A20 (P1.10)
P1.11: U1.P$B19 (P1.11)
P1.12: U1.P$B17 (P1.12)
P1.13: U1.P$A16 (P1.13)
P1.14: U1.P$B15 (P1.14)
P1.15: U1.P$A14 (P1.15)
PMIC_INT: IC1.A1 (!INT), U1.P$T2 (P0.11)
RESET: J2.6, TP_RESET.TP, U1.P$AC13 (P0.18/RESET)
SCK: U1.P$A12 (P0.02/AIN0); also elsewhere on the board
SCL: IC1.B1 (SCL), IC3.12 (SCX), R4.1, R17.2, TP_SCL.TP, U1.P$M2 (P0.07); also elsewhere on the board
SDA: IC1.C1 (SDA), IC3.2 (SDX), R2.1, R18.2, TP_SDA.TP, U1.P$L1 (P0.06); also elsewhere on the board
SWDCLK: J2.4, TP_SWDCLK.TP, U1.P$AA24 (SWDCLK)
SWDIO: J2.2, TP_SWDIO.TP, U1.P$AC24 (SWDIO)
SWO: TP_SWO.TP, U1.P$AD22 (P1.00)
VBAT: C37.2, IC1.C2 (BAT); also elsewhere on the board
VBUS: C21.1, C38.2, IC1.A2 (IN), U1.P$AD2 (VBUS); also elsewhere on the board
VREG: C23.2, C24.2, C39.1, IC1.B2 (SYS), IC9.A1 (EN), IC9.A2 (VIN_1), IC9.A3 (VIN_2), TP_VREG.TP

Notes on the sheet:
SWD
LiPo Charger
DC/DC
IMU
N.C
DEC4_6
DEC3
DEC1
P0.00/XL1
P0.01/XL2

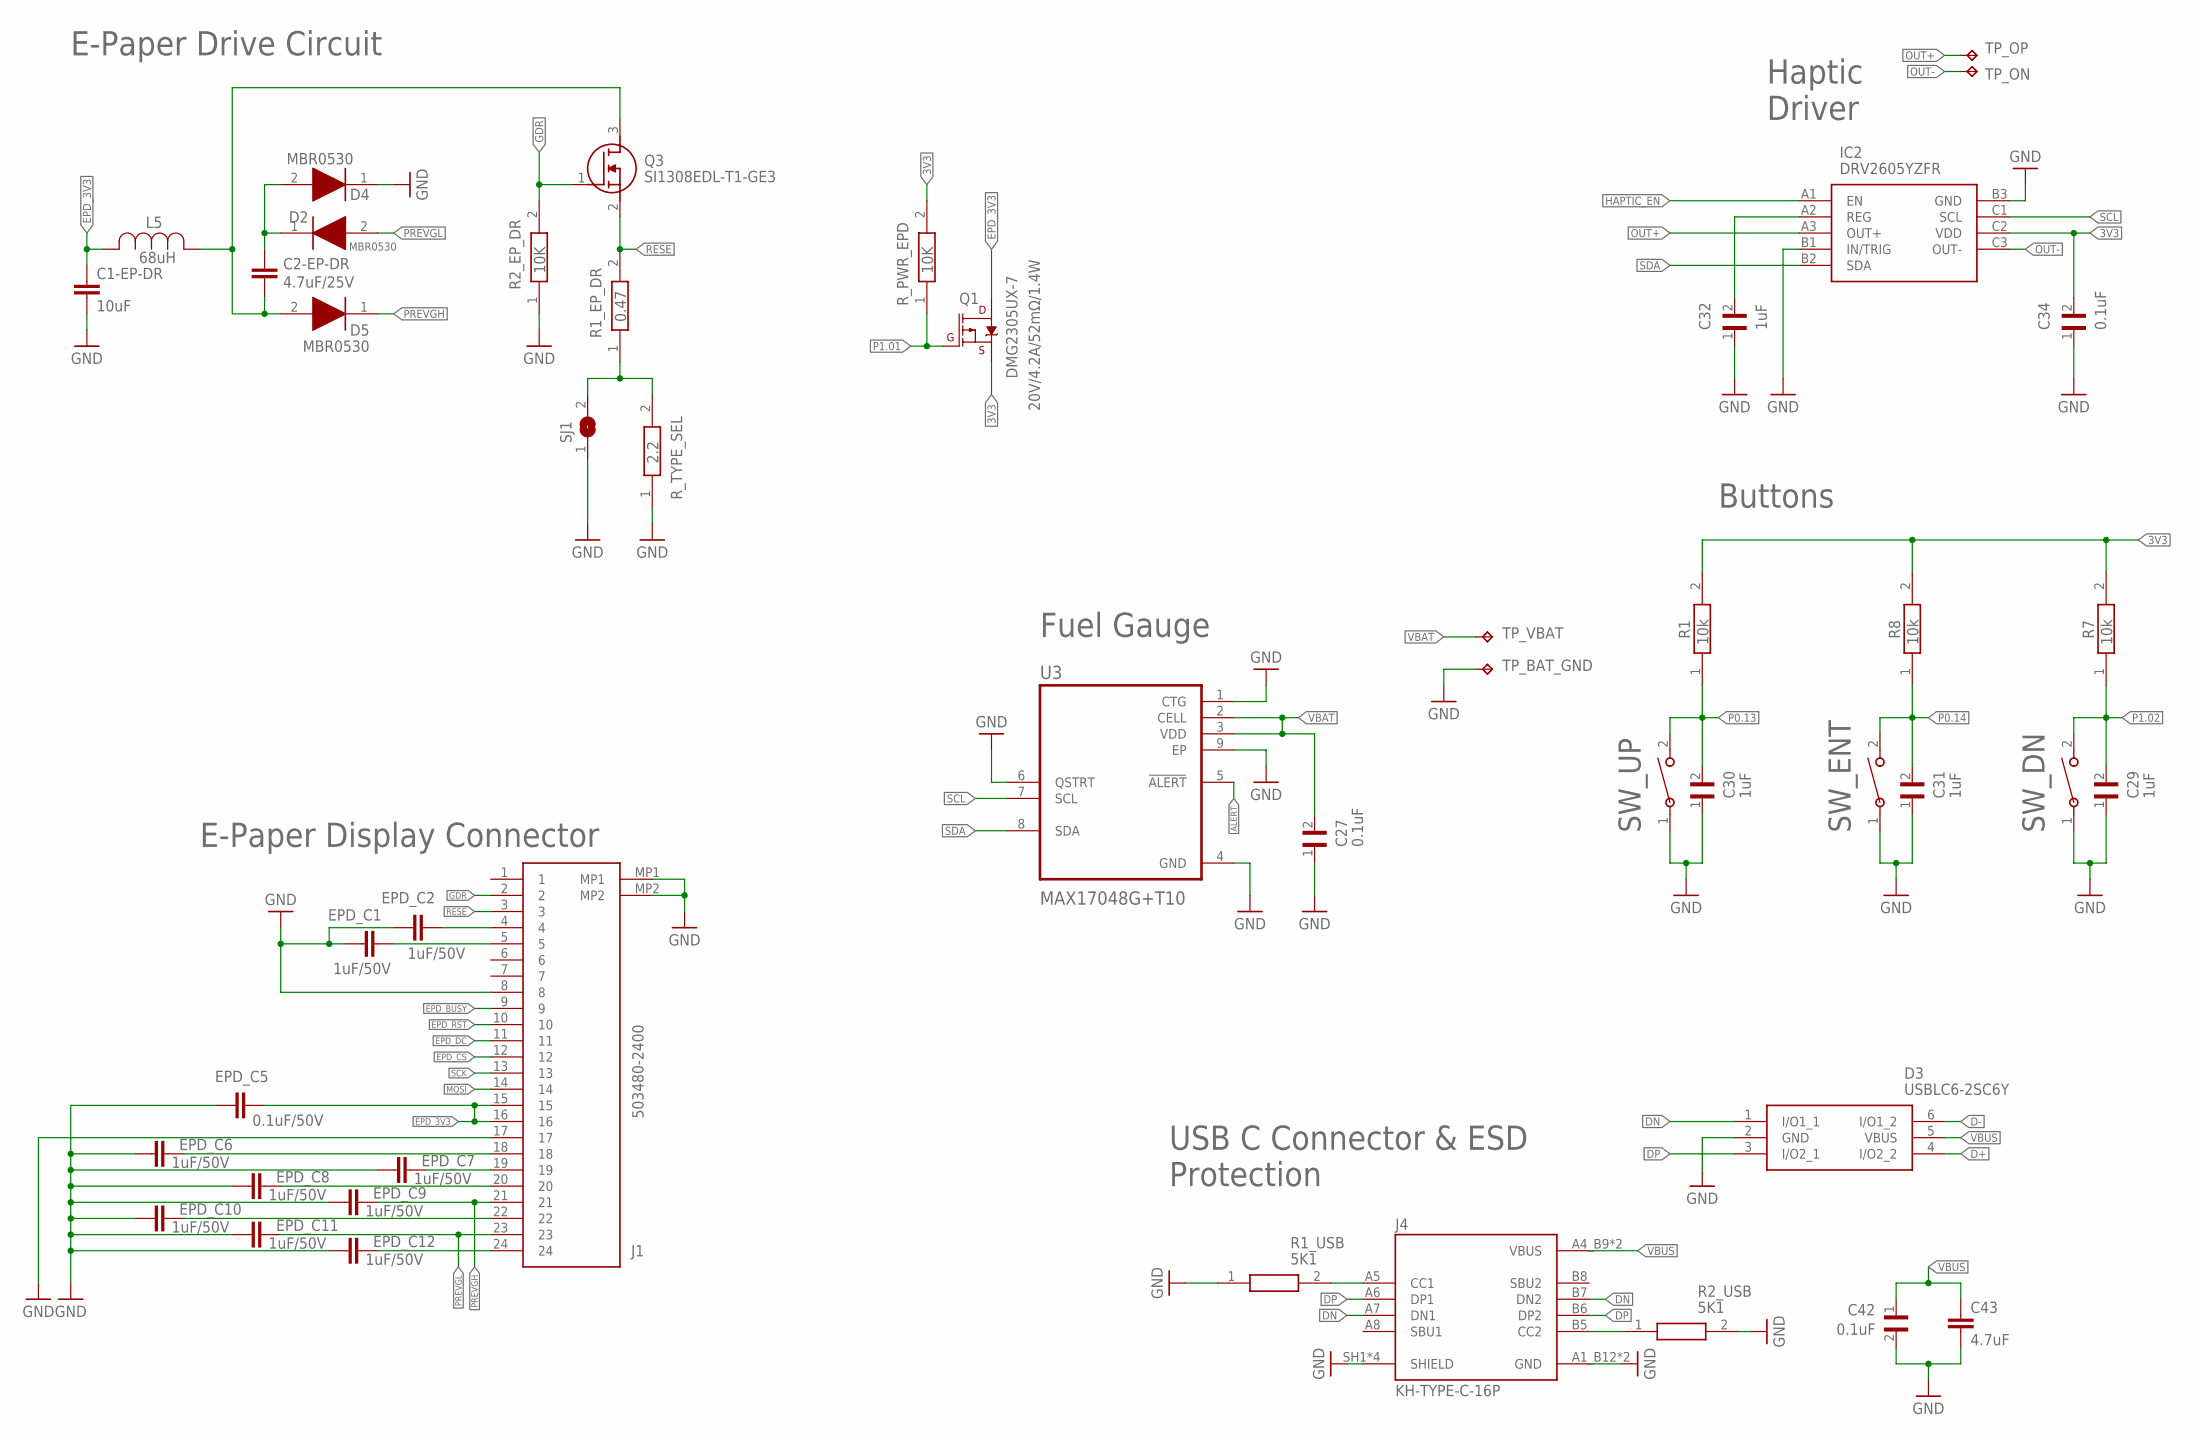
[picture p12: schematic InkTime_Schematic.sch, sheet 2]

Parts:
C1-EP-DR: 10uF; NORDIC_NRF_3_RESC0402_L
C2-EP-DR: 4.7uF/25V; NORDIC_NRF_3_RESC0402_L
C27, C34, C42: 0.1uF; GRM011R60J152KE01L_1_0201
C29, C30, C31, C32: 1uF; GRM011R60J152KE01L_1_0201
C43: 4.7uF; NORDIC_NRF_3_RESC0402_L
D2, D4, D5: MBR0530; ESP32_C6_LIBRARY_5_SOD3716X135N
D3: USBLC6-2SC6Y; ESP32_C6_LIBRARY_3_SOT95P280X145-6N
EPD_C1, EPD_C2, EPD_C6, EPD_C7, EPD_C8, EPD_C9, EPD_C10, EPD_C11, EPD_C12: 1uF/50V; NORDIC_NRF_3_RESC0402_L
EPD_C5: 0.1uF/50V; NORDIC_NRF_3_RESC0201_L
IC2: DRV2605YZFR; DRV2605YZFR_BGA9C50P3X3_144X144X62
J1: 503480-2400; 503480-2400_5034802400
J4: KH-TYPE-C-16P; KH-TYPE-C-16P_KINGHELM_KH-TYPE-C-16P
L5: 68uH; ESP32_C6_LIBRARY_2_IND_4828-WE-TPC_WRE
Q1: 20V/4.2A/52mΩ/1.4W; ESP32_C6_LIBRARY_4_ESP32_C6_LIBRARY_4_ESP32_C6_LIBRARY_4_ES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
Q3: SI1308EDL-T1-GE3; ESP32_C6_LIBRARY_6_SOT65P210X110-3N
R1, R7, R8: 10k; CPF0201D7K68C1_0201
R1_EP_DR: 0.47; CPF0201D7K68C1_0201
R1_USB, R2_USB: 5K1; CPF0201D7K68C1_0201
R2_EP_DR: 10K; CPF0201D7K68C1_0201
R_PWR_EPD: 10K; CPF0201D7K68C1_0201
R_TYPE_SEL: 2.2; CPF0201D7K68C1_0201
SJ1: ESP32_C6_LIBRARY_7_JUMPER_SJ
SW_DN: 2025-10-22_07-23-44_LIBRARY_EVP-AKE31ASW_EVP-AKE3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; 2025-10-22_07-23-44_LIBRARY_SW_EVP-AKE31A_PAN
SW_ENT: 2025-10-22_07-23-44_LIBRARY_EVP-AKE31ASW_EVP-AKE3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; 2025-10-22_07-23-44_LIBRARY_SW_EVP-AKE31A_PAN
SW_UP: 2025-10-22_07-23-44_LIBRARY_EVP-AKE31ASW_EVP-AKE3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; 2025-10-22_07-23-44_LIBRARY_SW_EVP-AKE31A_PAN
TP_BAT_GND: HECTOR_WATCH_1_TPTP20R; HECTOR_WATCH_1_TP20R
TP_ON: HECTOR_WATCH_1_TPTP20R; HECTOR_WATCH_1_TP20R
TP_OP: HECTOR_WATCH_1_TPTP20R; HECTOR_WATCH_1_TP20R
TP_VBAT: HECTOR_WATCH_1_TPTP20R; HECTOR_WATCH_1_TP20R
U3: MAX17048G+T10; ESP32_C6_LIBRARY_SON50P200X200X80-9N

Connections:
3V3: C34.2, IC2.C2 (VDD), Q1.2 (S), R1.2, R7.2, R8.2, R_PWR_EPD.2; also elsewhere on the board
ALERT: U3.5 (!ALERT); also elsewhere on the board
D+: D3.4 (I/O2_2); also elsewhere on the board
D-: D3.6 (I/O1_2); also elsewhere on the board
DN: D3.1 (I/O1_1), J4.A7 (DN1), J4.B7 (DN2)
DP: D3.3 (I/O2_1), J4.A6 (DP1), J4.B6 (DP2)
EPD_3V3: C1-EP-DR.1, EPD_C5.2, J1.15, J1.16, L5.2, Q1.3 (D)
EPD_BUSY: J1.9; also elsewhere on the board
EPD_CS: J1.12; also elsewhere on the board
EPD_DC: J1.11; also elsewhere on the board
EPD_RST: J1.10; also elsewhere on the board
GDR: J1.2, Q3.1 (G), R2_EP_DR.2
GND: C1-EP-DR.2, C27.1, C29.1, C30.1, C31.1, C32.1, C34.1, C42.2, C43.2, D3.2 (GND), D4.1 (K), EPD_C1.1, EPD_C2.1, EPD_C5.1, EPD_C6.1, EPD_C7.1, EPD_C8.1, EPD_C9.1, EPD_C10.1, EPD_C11.1, EPD_C12.1, IC2.B1 (IN/TRIG), IC2.B3 (GND), J1.8, J1.17, J1.MP1, J1.MP2, J4.A1_B12 (GND), J4.A12_B1 (GND), J4.SH1 (SHIELD), J4.SH2 (SHIELD), J4.SH3 (SHIELD), J4.SH4 (SHIELD), R1_USB.1, R2_EP_DR.1, R2_USB.2, R_TYPE_SEL.1, SJ1.1, SW_DN.1, SW_ENT.1, SW_UP.1, TP_BAT_GND.TP, U3.1 (CTG), U3.4 (GND), U3.6 (QSTRT), U3.9 (EP); also elsewhere on the board
HAPTIC_EN: IC2.A1 (EN); also elsewhere on the board
MOSI: J1.14; also elsewhere on the board
unnamed: C2-EP-DR.2, D5.2 (A), L5.1, Q3.3 (D)
unnamed: C2-EP-DR.1, D2.1 (K), D4.2 (A)
unnamed: R1_EP_DR.1, R_TYPE_SEL.2, SJ1.2
unnamed: J4.B5 (CC2), R2_USB.1
unnamed: C32.2, IC2.A2 (REG)
unnamed: EPD_C2.2, J1.4
unnamed: EPD_C1.2, J1.5
unnamed: EPD_C6.2, J1.18
unnamed: J4.A5 (CC1), R1_USB.2
unnamed: EPD_C7.2, J1.19
unnamed: EPD_C8.2, J1.20
unnamed: EPD_C10.2, J1.22
unnamed: EPD_C12.2, J1.24
OUT+: IC2.A3 (OUT+), TP_OP.TP
OUT-: IC2.C3 (OUT-), TP_ON.TP
P0.13: C30.2, R1.1, SW_UP.2; also elsewhere on the board
P0.14: C31.2, R8.1, SW_ENT.2; also elsewhere on the board
P1.01: Q1.1 (G), R_PWR_EPD.1; also elsewhere on the board
P1.02: C29.2, R7.1, SW_DN.2; also elsewhere on the board
PREVGH: D5.1 (K), EPD_C9.2, J1.21
PREVGL: D2.2 (A), EPD_C11.2, J1.23
RESE: J1.3, Q3.2 (S), R1_EP_DR.2
SCK: J1.13; also elsewhere on the board
SCL: IC2.C1 (SCL), U3.7 (SCL); also elsewhere on the board
SDA: IC2.B2 (SDA), U3.8 (SDA); also elsewhere on the board
VBAT: C27.2, TP_VBAT.TP, U3.2 (CELL), U3.3 (VDD); also elsewhere on the board
VBUS: C42.1, C43.1, D3.5 (VBUS), J4.A4_B9 (VBUS), J4.A9_B4 (VBUS); also elsewhere on the board

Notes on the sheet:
E-Paper Drive Circuit
DMG2305UX-7
Haptic Driver
Buttons
USB C Connector & ESD Protection
Fuel Gauge
E-Paper Display Connector

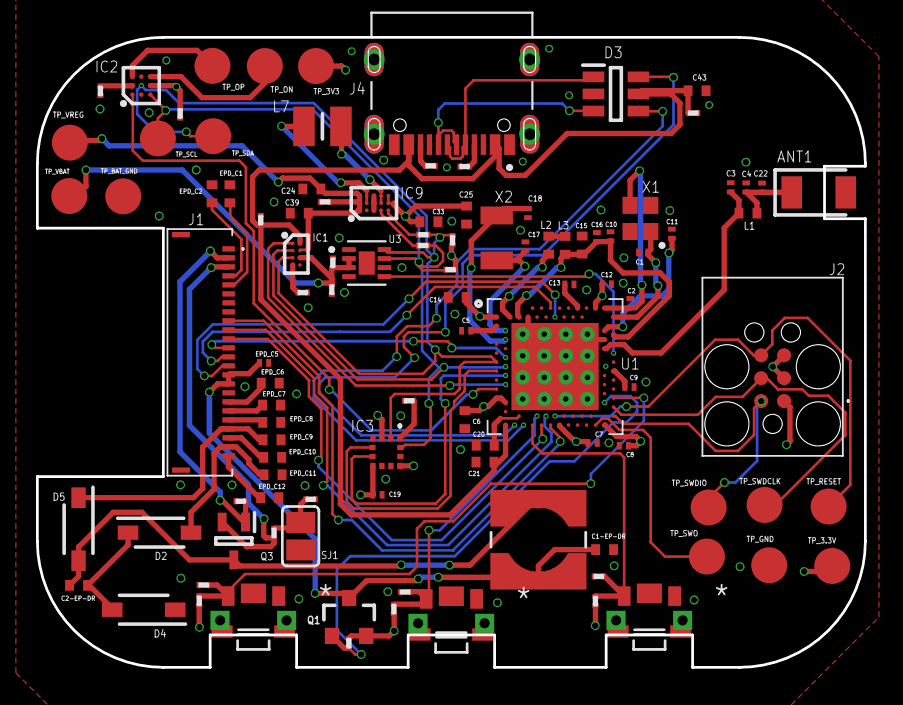
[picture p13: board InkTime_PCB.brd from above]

Board: 4 copper layers, 46.0 x 35.0 mm, 105 parts (0 on the bottom side), 70 nets.

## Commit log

2026-04-10 add schematic, PCB and manufacturing files
    [InkTime-PCB.brd, InkTime-Schematic.sch]
2026-04-10 add 3D PCB
2026-04-20 final design
    [Bill_of_Materials.csv, InkTime-PCB.brd, InkTime-Schematic.sch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]

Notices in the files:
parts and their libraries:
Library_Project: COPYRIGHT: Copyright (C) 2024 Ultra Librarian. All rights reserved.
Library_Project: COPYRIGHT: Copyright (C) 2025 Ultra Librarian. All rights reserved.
